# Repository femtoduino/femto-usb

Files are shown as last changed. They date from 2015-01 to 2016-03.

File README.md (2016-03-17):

femto-usb
=========



FemtoUSB - Atmel ARM Cortex M0+ (SAMD21), 256KB @ 48MHz, 3V3

This micro controller is designed as a basic starting point for those interested in ARM designs (especially if you are transitioning from 8-bit AVR chips).

We use Atmel's ARM Cortex M0+ offering, the ATSAMD21E18A. The schematic follows the suggested design found in the SAM D21 data sheet.

## Arduino Setup (TLDR)

Arduino compatible when using FemtoUSB (ARM) r1.0.1, with RGB LED.

Just add us to your Arduino IDE. See README https://github.com/femtoio/ArduinoCore-atsamd21e18a/tree/atsamd21e18a_variant

## Why Atmel?
Atmel has some of the best support for the open-source hardware community. They offer proper documentation, excellent chip performance, and a great foundation via the Atmel Software Framework.
Did we mention how easy it is to get started with ARM using ATMEL?

## Key similarities, and differences between 8-bit AVR chips, and newer ARM chips

So, you've been working with Arduino boards for a while now, but want to get into ARM chips right? How difficult can it be?

As it turns out, it's much less so today than it was a short time ago. Thankfully, most micro controllers have a similar set of requirements:

1. Add in some snubbing caps, as per the chip's data sheet.
2. Add in some resistors, as per the chip's data sheet.
3. Add the reset circuit.
4. Add a "power on" LED, making sure to wire up voltage and ground pins correctly.
5. Hook up a USB port, as per the chip's data sheet.
6. Burn a boot loader.

You can of course, add in a reverse current protection circuit, a crystal clock source for chips that don't have an internal one (or if you want a faster clock source), some fancy peripheral additions, etc... but at the most basic design, both 8-bit AVR chips and ARM chips have similar design requirements.

However, here's where we will draw an imaginary line, and now distinguish between 8-bit AVRs and 16/32-bit ARM chips.

When working with ARM chips, you will need a programmer dongle to initially burn a boot loader. 
"Serial Wire Debug" seems to be the most basic form of the [JTAG](http://en.wikipedia.org/wiki/Joint_Test_Action_Group) interface - something provided by all ARM chips. 
This is akin to the "Ardiuno ISP" mode of programming. 
Keep in mind, however, not all chips "talk the same" between the chip and a dongle. Kind of like how two people can have the same interface (vocal chords), but speak different languages. 
Fortunately, it seems Atmel's SAM D21 chips talk "CMSIS" [Cortex Microcontroller Software Interface Standard](http://www.arm.com/products/processors/cortex-m/cortex-microcontroller-software-interface-standard.php), which is a vendor-independent hardware abstraction layer for the Cortex-M processor series.
This is another great reason to use Atmel's line of ARM chips, for what it's worth.

The pins used to provide a JTAG connection vary depending on the ARM chip used, and provide more debugging features when more pins are added.
For the most part, JTAG "Serial Wire Debug" establishes these five (5) connections:

* Ground
* Voltage Reference (Does not supply voltage, you must tie your regulated voltage source to this line when connecting a dongle to a board)
* RESET
* SWCLK (Serial Wire Clock, sometimes overlaid on the "TCK" pin)
* SWDIO (Serial Wire Debug Input/Output, sometimes overlaid on the "TMS" pin)

Your programming dongle should have a data sheet telling you the pin out provided, so you can wire it to your board accordingly.

Another key difference, *and a very important one at that*, is the voltage!

You may be used to 5V logic levels working with Atmel's 8-bit chips... but 5V can be utterly destructive to an ARM chip, as they are meant to work with less power.
The usual voltage range for Atmel's line of ARM chips is somewhere between 1.8V to 3.3V. 
Failure to heed this notice will likely result in the production of a tiny paperweight, instead of a micro controller. 

Ok, I suppose we can move forward. Let's get everything we need to build one.

## Building your own board
The following instructions should help you build your own ARM board. Please follow common workplace and ESD safety practices, and ensure proper ventilation. Solder paste, solder rework, PCB fibers, hot air rework nozzles, soldering irons, and so on, should all be handled with proper safety in mind.
Please observe you local materials safety and disposal laws/guides. We assume no liability whatsoever. Not even. Just no.

### Equipment
As with all ARM chips, you will benefit greatly from having a programmer dongle.
Some vendors lock their chips behind really expensive software tools, and even more expensive programmer dongles ($200+). 
Oh, and have fun trying to get their proprietary stuff working with your open source setup.

Thankfully, Atmel offers their ATMEL-ICE programmer at a reasonable price of [about $85 USD](http://store.atmel.com/PartDetail.aspx?q=p:10500375#tc:description).
I hear you can get them much cheaper without the case, though don't expect it to come with ribbon cables if you go the cheap route.

Please source the following equipment:
* An [ATMEL-ICE programmer](http://www.atmel.com/tools/atatmel-ice.aspx)
* A Windows, Mac OS X, or Linux machine. (Though you may initially require a Windows machine to burn the SAM-BA bootloader using Atmel Studio.)
* Two (2) USB "Micro B" cable. Some cables are less than useless. Try to use ones without a choke if you get any trouble with USB connections.
* Round jumper wires.
* Bread board.
* A reflow station. We use a [Sparkfun Hot-air Rework Station](https://www.sparkfun.com/products/10706)
* A good pair of tweezers. See [Adafruit's offering](http://www.adafruit.com/products/421?gclid=CN-E8eah5MMCFU9efgodj3IAJQ)
* [Helping third hand](http://www.adafruit.com/product/291)
* A multimeter.

Additionally, you will need the following supplies:
* Low temp Lead-free solder paste. We recommend [Pieco's  paste press dispenser bundle with the ChipQuik T5 paste](https://www.tindie.com/products/Pieco/paste-press/) or similar.  
* Some PCBs. You can order them from [OSH Park](https://oshpark.com/shared_projects/F0wPGZvV), or open up the Eagle PCB designs to modify and make your own (see the FemtoUSB_r1.0.0 folder, open up the femtoUSB_r1.0.0_TQFP board and schematic)
* The SMD components. [Thanks Octopart!](https://octopart.com/bom-lookup/UgbhotEt) ...the gerbers and parts lists can also be found within the `FemtoUSB_r1.0.0/femtoUSB_r1.0.0_TQFP/` folder

### Software tools
On windows, you will need
* Atmel Studio (6.2.x as of the time of this writing)

On Mac OS X, and Linux
* [Terry Guo's GNU ARM Embedded Toolchain.](https://launchpad.net/~terry.guo/+archive/ubuntu/gcc-arm-embedded) (Ubuntu user's can add a PPA and have the apt-get package manager install it)
* Legit command line ninja skills.
* Make tools.

For any machine you are on, you will also need the following:

* [Atmel Software Framework (ASF)](http://www.atmel.com/tools/avrsoftwareframework.aspx?tab=overview)
* [Atmel SAM-BA In-system Programmer](http://www.atmel.com/tools/ATMELSAM-BAIN-SYSTEMPROGRAMMER.aspx)
* [Atmel AT07175: SAM-BA Bootloader for SAM D21](http://www.atmel.com/devices/atsamd21e18a.aspx?tab=documents) ...Note, this is what actually gets programmed on to the chip so we can load stuff via USB instead.

### Assembling a board, or three.
For the most part, try not to make a mess of solder paste everywhere. Add just enough to cover the solder pads with a thin layer, and place the correct part according to the femtoUSB_r1.0.0_TQFP_parts.csv spread sheet.
If you don't have the 4-layer or more version of Eagle PCB, you can also look at the femtoUSB_r1.0.0_TQFP.pdf file for schematics and board drawings. See `FemtoUSB_r1.0.0/femtoUSB_r1.0.0_TQFP/`

Once you have everything assembled, make sure your board is secured by the "helping third hand" tool, and remove any nozzle attachments from your reflow station to get the widest air flow. 
Heat up your reflow station to around 200c - 210c or so. The low temperature lead-free solder paste should not require too much heat. Air flow should be kept low (I dial it down to level 4 on my Sparkfun Hot-air Rework station).
Go ahead and adjust the temperature and air flow as you see fit. A constant stream of hot air should reflow stuff within a minute or less.

Be certain to keep the air flow on the USB connection a bit longer than the rest of the board, as the pads underneath the USB connector may take a few seconds longer to heat up.

*Allow your boards to cool down on their own before handling!*

### Testing and programming
Grab you multimeter, switch it to the "open circuit" checking mode (you know, the one that beeps when touch the two leads).
Test between the GND (Ground) pin and all other pins to assert there are no shorts between Ground and the rest of the pins. 
Do the same between voltage and other pins. As a last step, you can also test by steping pegs, (testing between two concurrent pins, moving up by one pin at a time).
This last step is mostly necessary if you have a hard time checking the board for shorts or gaps visually.

Now, it's time to give our board(s) a bootloader!

Wire the following pins together, tying the two "GND" pins from the ATMEL-ICE programmer dongle on to a breadboard, so you can use a single wire from the breadboard GND line to the board's GND pin.
Additionally, you will need to make sure the board's 3V3 (regulated) volatage pin is tied to the programmer dongle's VTG (voltage reference) pin, as the programmer dongle does *not* supply voltage. It merely detects the voltage level with the VREF line.

*DO NOT MIX UP THE "SAM" PORT WITH THE "AVR" PORT, AS THE PINOUT IS DIFFERENT!*

| ATMEL-ICE "SAM" port | Your Board |
|---|---|
| SWDCLK (SAM Pin 4) | SWDCLK (PA31)  |
| SWDIO (SAM Pin 2) | SWDIO (PA30) |
| nRST (SAM Pin 10, labeled "0") | RESET |
| VTG (SAM Pin 1) | 3V3 (Regulated)|
| GND (SAM Pin 3, 5) | GND |

#### Windows
Open up Atmel Studio on your Windows machine, plug in the USB cable for your board, plug in the USB cable for your programmer dongle.
Your board should power on, the programmer should have both a red LED and a green LED powered on.

If only the red programmer dongle LED turns on, check for loose connections and check for any solder issues on your board. At worse, build another one with a different PCB and try again.
Don't worry about the semi-on blue LED on your board. That's just the SWDCLK line. You can unsolder it if it bugs you. 

Once you have a good board hooked up, and Atmel Studio running, open up the Device Programmer dialog by navigating to the Tools -> Device Programmer menu item.

In the Device Programmer dialog, select "ATMEL-ICE" as the tool, select "ATSAMD21E18A" as the device (double check to be certain you read this right), and select "SWD" as the interface. 
Click the "Apply" button. Set the "SWD Clock" value to anything from 32KHz to 2MHz and click "Set".
2MHz is plenty fast, but if you ever run into issues reading the chip, try going as low as 32KHz.

You should now click the "Read" button under "Device Signature" to see if you get back a hex value. The board's blue LED will go from semi-off, to bright blue.
If you get a message saying your device is unreadable, double check your connections, double check your solder work, and try again.

Assuming you got back a hex value under "Device Signature", congrats! You appear to have a functional board!

Let's now burn the bootloader.

Click the "Memories" section of the Device Programmer dialog. In the "Flash" area, use the file navigator button to browse to the downloaded (and extracted) `Atmel-42366-SAM-BA-Bootloader-for-SAM-D21_ApplicationNote_AT07175/load sam-ba/samd21e18a/` folder, and select `samd21_sam_ba_usbcdc.hex`
Assert the "Erase Flash before programming" and "Verify Flash after programming" checkboxes are checked. Click "Program". After a brief moment, the Device Programmer dialog should come back with:

```
Erasing device... OK
Programming Flash...OK
Verifying Flash...OK
```

Success! You now have a board with the SAM-BA bootloader! If you're on a Windows machine, you may notice Windows will now attempt to install drivers for the new device. The Windows driver install tool should succeed in finding the correct drivers.
You can now see your board on Linux/Mac as well. Simply plug it in via USB, and run the 'lsusb' command from a terminal. You will see an Atmel 'SAM-BA' device listing.

#### GNU/Linux (Ubuntu)

You will need to install Terry Guo's arm-none-eabi-* toolchain, OpenOCD, and the build-essentails package.

To load stuff over USB CDC, you will need either Atmel's SAM-BA utility, or the 'arduino' branch of the BOSSA utility (compiled from source). See https://github.com/femtoio/BOSSA

```
# Thanks to Patryk Jaworski for a wonderful blog article
# http://regalis.com.pl/en/arm-cortex-stm32-gnulinux/
openocd -f /path/to/boardconfig.cfg
```
Then, in a separate terminal:
```
telnet localhost 4444
```
...Run the following within telnet:
```
reset halt
flash write_image erase yourfile.hex
reset run
```

## Next Steps
We are working on getting Arduino integration working, along with other non-Arduino tools to load stuff via USB. Stay tuned!

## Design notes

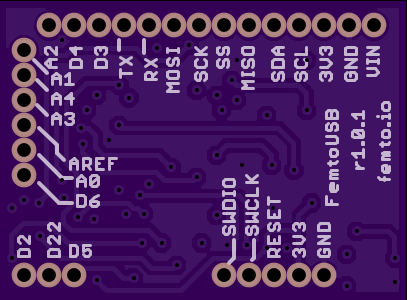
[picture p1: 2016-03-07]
FemtoUSB_r1.0.1/femtoUSB_RGB_r1.0.1_bottom.png

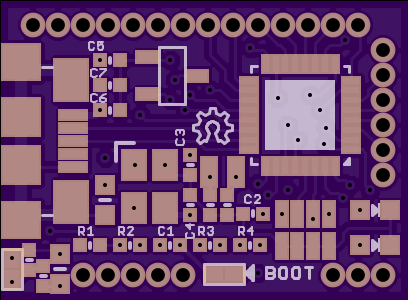
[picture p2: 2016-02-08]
FemtoUSB_r1.0.1/femtoUSB_r1.0.1_top.png

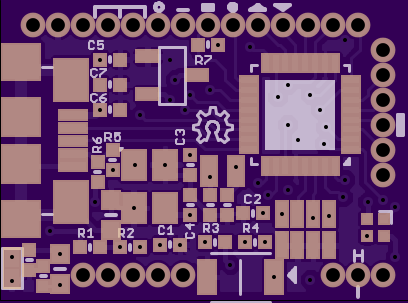
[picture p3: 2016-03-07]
FemtoUSB_r1.0.1/femtoUSB_RGB_r1.0.1_top.png

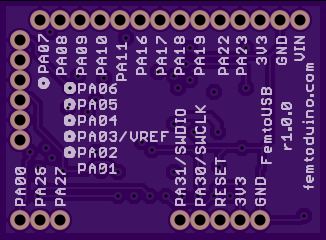
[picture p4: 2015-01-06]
FemtoUSB_r1.0.1/femtoUSB_bottom.png

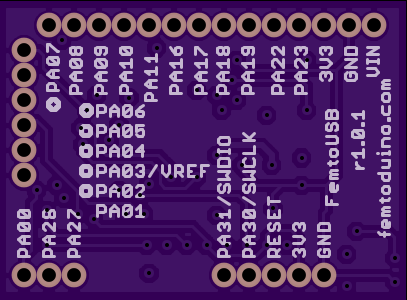
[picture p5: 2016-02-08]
FemtoUSB_r1.0.1/femtoUSB_r1.0.1_bottom.png

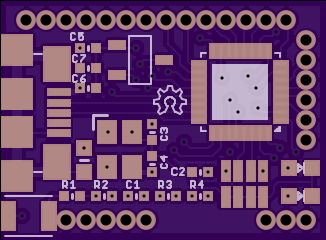
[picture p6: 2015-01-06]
FemtoUSB_r1.0.1/femtoUSB_top.png

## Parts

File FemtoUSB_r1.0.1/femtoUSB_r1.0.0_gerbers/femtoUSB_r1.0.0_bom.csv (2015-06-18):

Qty | Value | Device | Package | Parts | Description | DIGIKEY_PART/MNF_PART
1 |  | FERRITE_0603MP | _0603MP | FB1 | Ferrite Bead | BLM18RK102SN1D
1 | 0.1uF | CAP_CERAMIC_0402MP | _0402MP | C1 | Ceramic Capacitors | GRM033C80J104KE84D
1 | 0.1uF | KEMET_CERAMIC_CAPACITOR_ARRAY_1X4 | CAPACITOR_ARRAY_1206_MONO_1X4 | C_ARR1 |  | CA064C104K4RACTU
1 | 0.47uF | CAP_CERAMIC_0402MP | _0402MP | C7 | Ceramic Capacitors | C1005X5R1C474K050BC
1 | 10K | RESISTOR_0402MP | _0402MP | R2 | Resistors | CRCW040210K0JNEDHP
1 | 1X14_ROUND | 1X14_ROUND | 1X14_ROUND | U$6
1 | 1X3_ROUND | 1X3_ROUND | 1X3_ROUND | U$7
1 | 1X5_ROUND | 1X5_ROUND | 1X5_ROUND | U$9
1 | 1X6_ROUND | 1X6_ROUND | 1X6_ROUND | U$12
2 | 2.2uF | CAP_CERAMIC_0402MP | _0402MP | C5, C6 | Ceramic Capacitors | C1005X5R1C225K050BC
1 | 48MHz | TSX-3225 | TSX-3225 | EPSON_TSX1 |  | FA-238 48.0000MB-K3
3 | 330 | RESISTOR_0402MP | _0402MP | R1, R3, R4 | Resistors | CRCW0402330RJNED
1 | 4.7uF | CAP_CERAMIC_0402MP | _0402MP | C2 | Ceramic Capacitors | C1005X5R1A475K050BC
2 | 10pF | CAP_CERAMIC_0402MP | _0402MP | C3, C4 | Ceramic Capacitors | GRM0335C1E100JA01D
1 | ATSAMD21E18A-MUT | ATSAMD21E18A-MUT | QFN32 | IC1 | This is the ATMEL SAMD21E QFN-32 (ATSAMD21E18A-MU). The QFP version is ATSAMD21E18A-AU | ATSAMD21E18A-MUT
1 | BLUE | LED0603_NOOUTLINE | CHIPLED_0603_NOOUTLINE | LED2 | LED | 350-2037-1-ND
1 | MCP1700T-3302E/TT | MCP1700T-3302E/TT | MCP1700T-3302E/TT | LDO_VREG |  | MCP1700T-3302E/TT
1 | YELLOW | LED0603_NOOUTLINE | CHIPLED_0603_NOOUTLINE | LED1 | LED | 350-2032-1-ND
1 | USB_MICROB | USB_MICROB | USB_MICROB_PACKAGE | MICRO_B_USB | This is the hirose ZX62-B-5PA(11) MICRO-USB B Type female connection. | ZX62-B-5PA(11)
1 | 10uH | INDUCTOR_0603MP | _0603MP | L1 |  | LQM18FN100M00D
2 | 10uF | CAP_CERAMIC_0402MP | _0402MP | C8, C9 |  | CL05A106MP5NUNC

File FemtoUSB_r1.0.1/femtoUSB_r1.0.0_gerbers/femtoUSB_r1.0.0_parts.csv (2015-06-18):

Part | Value | Device | Package | Description
C1 | 0.1uF | CAP_CERAMIC_0402MP | _0402MP | Ceramic Capacitors
C2 | 4.7uF | CAP_CERAMIC_0402MP | _0402MP | Ceramic Capacitors
C3 | 10pF | CAP_CERAMIC_0402MP | _0402MP | Ceramic Capacitors
C4 | 10pF | CAP_CERAMIC_0402MP | _0402MP | Ceramic Capacitors
C5 | 2.2uF | CAP_CERAMIC_0402MP | _0402MP | Ceramic Capacitors
C6 | 2.2uF | CAP_CERAMIC_0402MP | _0402MP | Ceramic Capacitors
C7 | 0.47uF | CAP_CERAMIC_0402MP | _0402MP | Ceramic Capacitors
C8 | 10uF | CAP_CERAMIC_0402MP | _0402MP | Ceramic Capacitors
C9 | 10uF | CAP_CERAMIC_0402MP | _0402MP | Ceramic Capacitors
C_ARR1 | 0.1uF | KEMET_CERAMIC_CAPACITOR_ARRAY_1X4 | CAPACITOR_ARRAY_1206_MONO_1X4
EPSON_TSX1 | 48MHz | TSX-3225 | TSX-3225 | FA-238 48.0000MB-K3
FB1 |  | FERRITE_0603MP | _0603MP | Ferrite Bead
IC1 | ATSAMD21E18A-MUT | ATSAMD21E18A-MUT | QFN32 | This is the ATMEL SAMD21E QFN-32. ATSAMD21E18A
L1 | 10uH | INDUCTOR_0603MP | _0603MP | Fixed Inductor.
LDO_VREG | LM3480 | LM3480 | LM3480
LED1 | RED | LED0603_NOOUTLINE | CHIPLED_0603_NOOUTLINE | LED
LED2 | GREEN | LED0603_NOOUTLINE | CHIPLED_0603_NOOUTLINE | LED
MICRO_B_USB | USB_MICROB | USB_MICROB | USB_MICROB_PACKAGE | This is the hirose ZX62-B-5PA(11) MICRO-USB B Type female connection.
R1 | 330 | RESISTOR_0402MP | _0402MP | Resistors
R2 | 10K | RESISTOR_0402MP | _0402MP | Resistors
R3 | 330 | RESISTOR_0402MP | _0402MP | Resistors
R4 | 330 | RESISTOR_0402MP | _0402MP | Resistors
U$6 | 1X14_ROUND | 1X14_ROUND | 1X14_ROUND | 1.27mm Pitch
U$7 | 1X3_ROUND | 1X3_ROUND | 1X3_ROUND | 1.27mm Pitch
U$9 | 1X5_ROUND | 1X5_ROUND | 1X5_ROUND | 1.27mm Pitch
U$12 | 1X6_ROUND | 1X6_ROUND | 1X6_ROUND | 1.27mm Pitch

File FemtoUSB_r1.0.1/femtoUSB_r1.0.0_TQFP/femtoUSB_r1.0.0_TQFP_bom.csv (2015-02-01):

Qty | Value | Device | Package | Parts | Description | DIGIKEY_PART
1 |  | BLM18RK102SN1D | _0603MP | FB1 | Ferrite Bead | 490-5228-1-ND
1 | 0.1uF | C1005X7R1A104K050BB | _0402MP | C1 | Ceramic Capacitors | 445-4958-1-ND
1 | 0.1uF | CA064C104K4RACTU | CAPACITOR_ARRAY_1206_MONO_1X4 | C_ARR1 |  | 399-8243-1-ND
1 | 0.47uF | C1005X5R1C474K050BC | _0402MP | C7 | Ceramic Capacitors | 445-4976-1-ND
1 | 10K | CRCW040210K0JNEDHP | _0402MP | R2 | Resistors | 541-10KYACT-ND
1 | DNP | 1X14_ROUND | 1X14_ROUND | U$6
1 | DNP | 1X3_ROUND | 1X3_ROUND | U$7
1 | DNP | 1X5_ROUND | 1X5_ROUND | U$9
1 | DNP | 1X6_ROUND | 1X6_ROUND | U$12
2 | 2.2uF | C1005X5R1C225K050BC | _0402MP | C5, C6 | Ceramic Capacitors | 445-9085-1-ND
1 | 26MHz | TSX-3225 26.0000MF09Z-AC3 | TSX-3225 | EPSON_TSX1 |  | SER3627CT-ND
3 | 330 | CRCW0402330RJNED | _0402MP | R1, R3, R4 | Resistors | 541-330JCT-ND
1 | 4.7uF | C1005X5R1A475K050BC | _0402MP | C2 | Ceramic Capacitors | 445-13820-1-ND
2 | 9pF | C1005C0G1H090C050BA | _0402MP | C3, C4 | Ceramic Capacitors | 445-4894-1-ND
1 | ATSAMD21E18A-AU | ATSAMD21E18A-AU | 32-TQFP | IC1 |  | ATSAMD21E18A-AU-ND
1 | BLUE | 598-8091-107F | CHIPLED_0603_NOOUTLINE | LED2 | Blue LED | 350-2037-1-ND
1 | MCP1700T-3302E/TT | MCP1700T-3302E/TT | MCP1700T-3302E/TT | LDO_VREG |  | MCP1700T3302ETTCT-ND
1 | DNP | SPST_SMD | SPST_SMD | BTN
1 | YELLOW | 598-8040-107F | CHIPLED_0603_NOOUTLINE | LED1 | Yellow LED | 350-2032-1-ND
1 | USB_MICROB | ZX62-B-5PA(11) | USB_MICROB_PACKAGE | MICRO_B_USB | This is the hirose ZX62-B-5PA(11) MICRO-USB B Type female connection. | H11634CT-ND
1 | 10uH | LQM18FN100M00D | _0603MP | L1 |  | 490-4025-1-ND
2 | 10uF | CL05A106MP5NUNC | _0402MP | C8, C9 |  | 1276-1450-1-ND

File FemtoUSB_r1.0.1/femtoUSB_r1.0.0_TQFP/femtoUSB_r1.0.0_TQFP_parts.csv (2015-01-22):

Part | Value | Device | Package | Description | DIGIKEY_PART
BTN | OMRON B3U-300P(M) | TACTILE_SWITCH_NO_GND_NO_BOSS | SIDE_ACT_NO_GND_NO_BOSS
C1 | 0.1uF | CAP_CERAMIC_0402MP | _0402MP | Ceramic Capacitors
C2 | 4.7uF | CAP_CERAMIC_0402MP | _0402MP | Ceramic Capacitors
C3 | 9pF | CAP_CERAMIC_0402MP | _0402MP | Ceramic Capacitors
C4 | 9pF | CAP_CERAMIC_0402MP | _0402MP | Ceramic Capacitors
C5 | 2.2uF | CAP_CERAMIC_0402MP | _0402MP | Ceramic Capacitors
C6 | 2.2uF | CAP_CERAMIC_0402MP | _0402MP | Ceramic Capacitors
C7 | 0.47uF | CAP_CERAMIC_0402MP | _0402MP | Ceramic Capacitors
C_ARR1 | 0.1uF | KEMET_CERAMIC_CAPACITOR_ARRAY_1X4 | CAPACITOR_ARRAY_1206_MONO_1X4 |  | 399-8243-1-ND
EPSON_TSX1 | 32MHz | TSX-3225 | TSX-3225 |  | TSX-3225 32.0000MF15X-B-ND
FB1 |  | FERRITE_0603MP | _0603MP | Ferrite Bead
IC1 | ATSAMD21E18A-AU | ATSAMD21E18A-AU | 32-TQFP
LDO_VREG | MCP1700T-3302E/TT | MCP1700T-3302E/TT | MCP1700T-3302E/TT
LED1 | RED | LED0603_NOOUTLINE | CHIPLED_0603_NOOUTLINE | LED
LED2 | GREEN | LED0603_NOOUTLINE | CHIPLED_0603_NOOUTLINE | LED
MICRO_B_USB | USB_MICROB | USB_MICROB | USB_MICROB_PACKAGE | This is the hirose ZX62-B-5PA(11) MICRO-USB B Type female connection.
R1 | 330 | RESISTOR_0402MP | _0402MP | Resistors
R2 | 10K | RESISTOR_0402MP | _0402MP | Resistors
R3 | 330 | RESISTOR_0402MP | _0402MP | Resistors
R4 | 330 | RESISTOR_0402MP | _0402MP | Resistors
U$6 | 1X14_ROUND | 1X14_ROUND | 1X14_ROUND
U$7 | 1X3_ROUND | 1X3_ROUND | 1X3_ROUND
U$9 | 1X5_ROUND | 1X5_ROUND | 1X5_ROUND
U$12 | 1X6_ROUND | 1X6_ROUND | 1X6_ROUND

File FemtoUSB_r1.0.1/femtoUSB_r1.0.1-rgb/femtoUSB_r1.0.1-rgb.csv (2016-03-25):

Qty | Value | Device | Package | Parts | Description | MFR_ID
1 |  | FERRITE_0603MP | _0603MP | FB1 | Ferrite Bead | BLM18RK102SN1D
1 | DNP | SPST_SMD | SPST_SMD | SJ_RESET
1 | 0.1uF | CAP_CERAMIC_0402MP | _0402MP | C1 | Ceramic Capacitors | C1005X7R1A104K050BB
1 | 0.1uF | KEMET_CERAMIC_CAPACITOR_ARRAY_1X4 | CAPACITOR_ARRAY_1206_MONO_1X4 | C_ARR |  | CA064C104K4RACTU
1 | 0.47uF | CAP_CERAMIC_0402MP | _0402MP | C7 | Ceramic Capacitors | C1005X5R1C474K050BC
1 | 100K | RESISTOR_0402MP | _0402MP | R6 | Resistors | ERJ-2RKF1003X
1 | 10K | RESISTOR_0402MP | _0402MP | R2 | Resistors | CRCW040210K0JNEDHP
2 | 10uF | CAP_CERAMIC_0402MP | _0402MP | C8, C9 | Ceramic Capacitors | CL05A106MP5NUNC
1 | 10uH | INDUCTOR_0603MP | _0603MP | L1 | Inductors | LQM18FN100M00D
1 | DNP | 1X14_ROUND | 1X14_ROUND | PIN_1X14
1 | DNP | 1X3_ROUND | 1X3_ROUND | PIN_1X3
1 | DNP | 1X5_ROUND | 1X5_ROUND | PIN_1X5
1 | DNP | 1X6_ROUND | 1X6_ROUND | PIN_1X6
2 | 2.2uF | CAP_CERAMIC_0402MP | _0402MP | C5, C6 | Ceramic Capacitors | C1005X5R1C225K050BC
5 | 330 | RESISTOR_0402MP | _0402MP | R1, R3, R4, R5, R7 | Resistors | CRCW0402330RJNED
1 | 4.7uF | CAP_CERAMIC_0402MP | _0402MP | C2 | Ceramic Capacitors | C1005X5R1A475K050BC
1 | 48MHz | TSX-3225 | TSX-3225 | EPSON_TSX1 |  | FA-238 48.0000MB-K3
2 | 4pF | CAP_CERAMIC_0402MP | _0402MP | C10, C11 | Ceramic Capacitors | GJM1555C1H4R0CB01D
2 | 10pF | CAP_CERAMIC_0402MP | _0402MP | C3, C4 | Ceramic Capacitors | VJ0402A100FXACW1BC
1 | ABS06-107-32.768KHZ-T | ABS06-107-32.768KHZ-T | ABS06-107-32.768KHZ-T | OSC32K | ABS06-107-32.768kHz-T Crystal Oscillator | ABS06-107-32.768kHz-T
1 | ATSAMD21E18A-MUT | ATSAMD21E18A-MUT | QFN32 | IC1 | This is the ATMEL SAMD21E QFN-32. ATSAMD21E18A | ATSAMD21E18A-MUT
1 | LRTB_R48G | LRTB_R48G | LRTB_R48G | RGBLED |  | LRTB R48G
1 | MCP1700T-3302E/TT | MCP1700T-3302E/TT | MCP1700T-3302E/TT | LDO_VREG | Microchip LDO "MCP1700" in a 3-Pin SOT-23 package. | MCP1700T-3302E/TT
1 | TACTILE_SWITCH_NO_GND_NO_BOSS | TACTILE_SWITCH_NO_GND_NO_BOSS | SIDE_ACT_NO_GND_NO_BOSS | BTN_BOOT |  | B3U-3000PM
1 | USB_MICROB | USB_MICROB | USB_MICROB_PACKAGE | MICRO_B_USB | This is the hirose ZX62-B-5PA(11) MICRO-USB B Type female connection. | ZX62-B-5PA(11)

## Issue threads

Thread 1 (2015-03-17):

Arduino Hardware Core

pral2a, 2015-03-17:
We are really interested on developing and Arduino Hardware Core for the SAMD21 [Smart Citizen Kit](http://smartcitizen.me) project.

We are amazed by your idea of using ATMEL SAM-BA bootloader instead of the Arduino Zero EDBG approach.

https://github.com/femtoduino/femto-usb#next-steps

Do you think there is the possibility of joining forces on finishing this development?

Here is our main project repository

https://github.com/fablabbcn/Smart-Citizen-Kit

bobricius, 2015-03-17:
Hi, I tested today upload from arduino IDE 1.5.8.3 to atsamd21 xplained board and it working, also I flash provided bootloader and with this I canupload sketch to sam21 withou edbg chip from native usb port.

pral2a, 2015-03-17:
Thanks for the quick reply,

What cores did you use to target the atsamd21 from the Arduino IDE?

Thanks

bobricius, 2015-03-17:
I just select arduino zero from board menu, core is samd, you need ide from arduino.org not from arduino.cc
chaos begin .... two arduinos...

zrecommerce, 2015-03-18:
Really cool find, @bobricius! I'll verify with a FemtoUSB. I had to revise it once more to break out pin PA15 so the board can be put into boot loader moad after loading a sketch. The board I have at hand should be good.enough to test though, as the SAM-BA boot loader can be loaded.

zrecommerce, 2015-03-18:
FYI, found this while perusing `hardware/arduino/samd/variants/arduino_zero/variant.cpp` ...seems to be the Port/Pin map to Arduino Zero pinout.

```
/*
 *
 * + Pin number +  ZERO Board pin  |  PIN   | Label/Name      | Comments (* is for default peripheral in use)
 * +------------+------------------+--------+-----------------+------------------------------
 * |            | Digital Low      |        |                 |
 * +------------+------------------+--------+-----------------+------------------------------
 * | 0          | 0 -> RX          |  PA10  |                 | EIC/EXTINT[10] ADC/AIN[18] PTC/X[2] *SERCOM0/PAD[2] TCC1/WO[0] TCC0/WO[2]
 * | 1          | 1 <- TX          |  PA11  |                 | EIC/EXTINT[11] ADC/AIN[19] PTC/X[3] *SERCOM0/PAD[3] SERCOM2/PAD[3] TCC1/WO[1] TCC0/WO[3]
 * | 2          | ~2               |  PA08  |                 | EIC/NMI ADC/AIN[16] PTC/X[0] SERCOM0/PAD[0] SERCOM2/PAD[0] *TCC0/WO[0] TCC1/WO[2]
 * | 3          | ~3               |  PA09  |                 | EIC/EXTINT[9] ADC/AIN[17] PTC/X[1] SERCOM0/PAD[1] SERCOM2/PAD[1] *TCC0/WO[1] TCC1/WO[3]
 * | 4          | ~4               |  PA14  |                 | EIC/EXTINT[14] SERCOM2/PAD[2] SERCOM4/PAD[2] TC3/WO[0] *TCC0/WO[4]
 * | 5          | ~5               |  PA15  |                 | EIC/EXTINT[15] SERCOM2/PAD[3] SERCOM4/PAD[3] TC3/WO[1] *TCC0/WO[5]
 * | 6          | ~6               |  PA20  |                 | EIC/EXTINT[4] PTC/X[8] SERCOM5/PAD[2] SERCOM3/PAD[2] TC7/WO[0] *TCC0/WO[6]
 * | 7          | ~7               |  PA21  |                 | EIC/EXTINT[5] PTC/X[9] SERCOM5/PAD[3] SERCOM3/PAD[3] TC7/WO[1] *TCC0/WO[7]
 * +------------+------------------+--------+-----------------+------------------------------
 * |            | Digital High     |        |                 |
 * +------------+------------------+--------+-----------------+------------------------------
 * | 8          | ~8               |  PA06  |                 | EIC/EXTINT[6] PTC/Y[4] ADC/AIN[6] AC/AIN[2] SERCOM0/PAD[2] *TCC1/WO[0]
 * | 9          | ~9               |  PA07  |                 | EIC/EXTINT[7] PTC/Y[5] DC/AIN[7] AC/AIN[3] SERCOM0/PAD[3] *TCC1/WO[1]
 * | 10         | ~10              |  PA18  |                 | EIC/EXTINT[2] PTC/X[6] SERCOM1/PAD[2] SERCOM3/PAD[2] *TC3/WO[0] TCC0/WO[2]
 * | 11         | ~11              |  PA16  |                 | EIC/EXTINT[0] PTC/X[4] SERCOM1/PAD[0] SERCOM3/PAD[0] *TCC2/WO[0] TCC0/WO[6]
 * | 12         | ~12              |  PA19  |                 | EIC/EXTINT[3] PTC/X[7] SERCOM1/PAD[3] SERCOM3/PAD[3] *TC3/WO[1] TCC0/WO[3]
 * | 13         | ~13              |  PA17  | LED             | EIC/EXTINT[1] PTC/X[5] SERCOM1/PAD[1] SERCOM3/PAD[1] *TCC2/WO[1] TCC0/WO[7]
 * | 14         | GND              |        |                 |
 * | 15         | AREF             |  PA03  |                 | *DAC/VREFP PTC/Y[1]
 * | 16         | SDA              |  PA22  |                 | EIC/EXTINT[6] PTC/X[10] *SERCOM3/PAD[0] SERCOM5/PAD[0] TC4/WO[0] TCC0/WO[4]
 * | 17         | SCL              |  PA23  |                 | EIC/EXTINT[7] PTC/X[11] *SERCOM3/PAD[1] SERCOM5/PAD[1] TC4/WO[1] TCC0/WO[5]
 * +------------+------------------+--------+-----------------+------------------------------
 * |            |SPI (Legacy ICSP) |        |                 |
 * +------------+------------------+--------+-----------------+------------------------------
 * | 18         | 1                |  PA12  | MISO            | EIC/EXTINT[12] SERCOM2/PAD[0] *SERCOM4/PAD[0] TCC2/WO[0] TCC0/WO[6]
 * | 19         | 2                |        | 5V0             |
 * | 20         | 3                |  PB11  | SCK             | EIC/EXTINT[11]                *SERCOM4/PAD[3] TC5/WO[1] TCC0/WO[5]
 * | 21         | 4                |  PB10  | MOSI            | EIC/EXTINT[10]                *SERCOM4/PAD[2] TC5/WO[0] TCC0/WO[4]
 * | 22         | 5                |        | RESET           |
 * | 23         | 6                |        | GND             |
 * +------------+------------------+--------+-----------------+------------------------------
 * |            | Analog Connector |        |                 |
 * +------------+------------------+--------+-----------------+------------------------------
 * | 24         | A0               |  PA02  |                 | EIC/EXTINT[2] *ADC/AIN[0] PTC/Y[0] DAC/VOUT
 * | 25         | A1               |  PB08  |                 | EIC/EXTINT[8] *ADC/AIN[2] PTC/Y[14] SERCOM4/PAD[0] TC4/WO[0]
 * | 26         | A2               |  PB09  |                 | EIC/EXTINT[9] *ADC/AIN[3] PTC/Y[15] SERCOM4/PAD[1] TC4/WO[1]
 * | 27         | A3               |  PA04  |                 | EIC/EXTINT[4] *ADC/AIN[4] AC/AIN[0] PTC/Y[2] SERCOM0/PAD[0] TCC0/WO[0]
 * | 28         | A4               |  PA05  |                 | EIC/EXTINT[5] *ADC/AIN[5] AC/AIN[1] PTC/Y[5] SERCOM0/PAD[1] TCC0/WO[1]
 * | 29         | A5               |  PB02  |                 | EIC/EXTINT[2] *ADC/AIN[10] PTC/Y[8] SERCOM5/PAD[0] TC6/WO[0]
 * +------------+------------------+--------+-----------------+------------------------------
 * |            | LEDs             |        |                 |
 * +------------+------------------+--------+-----------------+------------------------------
 * | 30         |                  |  PB03  | RX              |
 * | 31         |                  |  PA27  | TX              |
 * +------------+------------------+--------+-----------------+------------------------------
 * |            | USB              |        |                 |
 * +------------+------------------+--------+-----------------+------------------------------
 * | 32         |                  |  PA28  | USB HOST ENABLE |
 * | 33         |                  |  PA24  | USB_NEGATIVE    | USB/DM
 * | 34         |                  |  PA25  | USB_POSITIVE    | USB/DP
 * +------------+------------------+--------+-----------------+------------------------------
 * |            | EDBG             |        |                 |
 * +------------+------------------+--------+-----------------+------------------------------
 * | 35         |                  |  PB22  | EDBG_UART TX    | SERCOM5/PAD[2]
 * | 36         |                  |  PB23  | EDBG_UART RX    | SERCOM5/PAD[3]
 * +------------+------------------+--------+-----------------+------------------------------
 * | 37         |                  |  PA22  | EDBG_SDA        | SERCOM3/PAD[0]
 * | 38         |                  |  PA23  | EDBG_SCL        | SERCOM3/PAD[1]
 * +------------+------------------+--------+-----------------+------------------------------
 * | 39         |                  |  PA19  | EDBG_MISO       | SERCOM1/PAD[3]
 * | 40         |                  |  PA16  | EDBG_MOSI       | SERCOM1/PAD[0]
 * | 41         |                  |  PA18  | EDBG_SS         | SERCOM1/PAD[2]
 * | 42         |                  |  PA17  | EDBG_SCK        | SERCOM1/PAD[1]
 * +------------+------------------+--------+-----------------+------------------------------
 * | 43         |                  |  PA13  | EDBG_GPIO0      | EIC/EXTINT[13] *TCC2/WO[1] TCC0/WO[7]
 * | 44         |                  |  PA21  | EDBG_GPIO1      | Pin 7
 * | 45         |                  |  PA06  | EDBG_GPIO2      | Pin 8
 * | 46         |                  |  PA07  | EDBG_GPIO3      | Pin 9
 * +------------+------------------+--------+-----------------+------------------------------
 * |            |32.768KHz Crystal |        |                 |
 * +------------+------------------+--------+-----------------+------------------------------
 * |            |                  |  PA00  | XIN32           | EXTINT[0] SERCOM1/PAD[0] TCC2/WO[0]
 * |            |                  |  PA01  | XOUT32          | EXTINT[1] SERCOM1/PAD[1] TCC2/WO[1]
 * +------------+------------------+--------+-----------------+------------------------------
 */
```

zrecommerce, 2015-03-18:
Trying to upload at the moment using the following in boards.txt ...but the compiler is choking. It seems SERCOM4 and SERCOM5 are not defined (and shouldn't be for the SAMD21E18A). I'm attempting to fix.

```
#FEMTOUSB (WITH) BOOTLOADER - NATIVE PORT
femtousb.name=FemtoUSB
femtousb.vid.0=0x03eb
femtousb.pid.0=0x6124
femtousb.upload.tool=openocd
femtousb.upload.protocol=sam-ba
femtousb.upload.maximum_size=262144
femtousb.upload.use_1200bps_touch=false
femtousb.upload.wait_for_upload_port=false
femtousb.upload.native_usb=true
femtousb.build.mcu=cortex-m0plus
femtousb.build.f_cpu=48000000L
femtousb.build.usb_product="Femto.io"
femtousb.build.usb_manufacturer="Femtoduino"
femtousb.build.board=SAM_ZERO
femtousb.build.core=arduino
femtousb.build.extra_flags=-D__SAMD21E18A__ -mthumb {build.usb_flags}
femtousb.build.ldscript=linker_scripts/gcc/flash_with_bootloader.ld
femtousb.build.openocdscript=openocd_scripts/arduino_zero.cfg
femtousb.build.variant=arduino_zero
femtousb.build.variant_system_lib=
femtousb.build.vid=0x03eb
femtousb.build.pid=0x6124
femtousb.build.section.start=0x4000
```

zrecommerce, 2015-03-18:
As a matter of fact, `hardware/tools/CMSIS/Device/ATMEL/samd21/include/samd21e18.h` defines SERCOM0 through SERCOM3, but not SERCOM4 and SERCOM5. Doesn't exist on the SAMD21E18A, yet it's expected by the rest of the Arduino C++ scripts. Perhaps a "bug" in the arduino hardware files?

zrecommerce, 2015-03-18:
Using Arduino 1.5.8.3 (from Arduino.org, not Arduino.cc)

I used the following in boards.txt, modified SERCOM.cpp and variant.cpp.

`hardware/arduino/samd/boards.txt`
```
#FEMTOUSB (WITH) BOOTLOADER - NATIVE PORT
femtousb.name=FemtoUSB
femtousb.vid.0=0x03eb
femtousb.pid.0=0x6124
femtousb.upload.tool=openocd
femtousb.upload.protocol=sam-ba
femtousb.upload.maximum_size=262144
femtousb.upload.use_1200bps_touch=false
femtousb.upload.wait_for_upload_port=false
femtousb.upload.speed=57600
femtousb.upload.native_usb=true
femtousb.build.mcu=cortex-m0plus
femtousb.build.f_cpu=48000000L
femtousb.build.usb_product="Femto.io"
femtousb.build.usb_manufacturer="Femtoduino"
femtousb.build.board=SAM_ZERO
femtousb.build.core=arduino
femtousb.build.extra_flags=-D__SAMD21E18A__ -mthumb {build.usb_flags}
femtousb.build.ldscript=linker_scripts/gcc/flash_with_bootloader.ld
femtousb.build.openocdscript=openocd_scripts/arduino_zero.cfg
femtousb.build.variant=arduino_zero
femtousb.build.variant_system_lib=
femtousb.build.vid=0x03eb
femtousb.build.pid=0x6124
femtousb.build.section.start=0x4000
```

`hardware/arduino/samd/cores/arduino/SERCOM.cpp:588`
```
void SERCOM::initClockNVIC( void )
{
	uint8_t clockId = 0;
	IRQn_Type IdNvic;
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

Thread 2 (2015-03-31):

crystall less operation?

bobricius, 2015-03-31:
hi, I am arm newbie but I read somewhere that atsamd21 have crystall less usb operation, do you anybody tested any bootloader work without crystal?

zrecommerce, 2015-04-03:
According to the docs, it has internal clocks for this...but I've also read about issues (USB won't work?)

...I'll give it a go and see what happens

bobricius, 2015-04-03:
for compatbility with arduino zero I  have plan add 32khz crystall.

zrecommerce, 2015-06-18:
The SAM D21 should operate with a 48MHz crystal. I wouldn't recommend a crystal-less operation unless USB isn't a big deal.

Closed 2015-06-18.

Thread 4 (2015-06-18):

32MHz Crystal in the Schematic but 26MHz in the BOM/Partlist

michaelkroll, 2015-06-18:
Hi,
I recognized that the value for the crystal is different in the BOM and Schematic.
Is this a fault of on purpose.
Moreover it seems that the PCB on OSHPark does not yet include the crystal. Will you upload the PCB design with the crystal as well. I want to test the setting out you are providing here and already ordered the PCB from OSHPark and some parts from digikey. Thanks for your help.

Best
Michael.

zrecommerce, 2015-06-18:
Hello Michael,

I've updated the Gerbers, and BoM/Partslist for the FemtoUSB (QFN version, not QFP) in the latest commit to the master branch ( a8d56e28d1379ceb3dbb5027a026c719701cb8d2 )

If you need the most recent Bill of Materials, you can see my list on octopart as well:
https://octopart.com/bom-lookup/UgbhotEt

- Alex

Closed 2015-06-18.

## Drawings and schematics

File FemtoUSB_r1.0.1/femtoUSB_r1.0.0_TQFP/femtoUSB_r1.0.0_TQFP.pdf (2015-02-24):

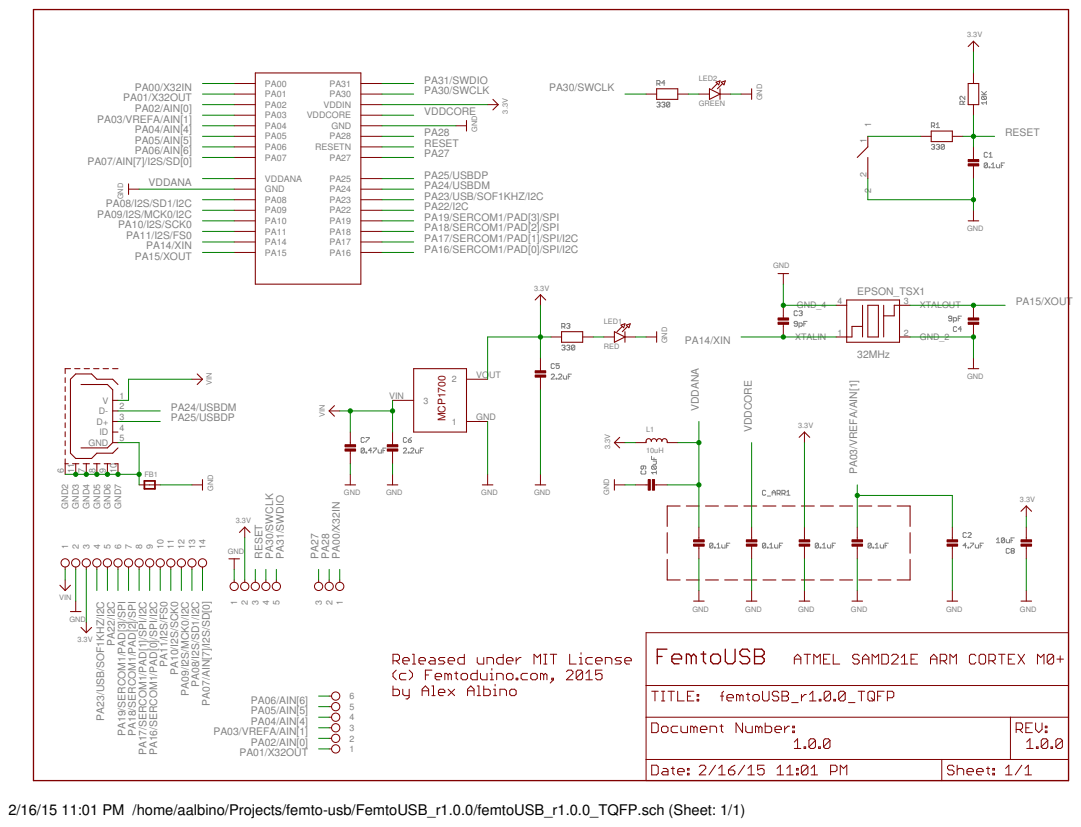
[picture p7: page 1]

VIN GND GND GND

2/16/15 11:01 PM /home/aalbino/Projects/femto-usb/FemtoUSB_r1.0.0/femtoUSB_r1.0.0_TQFP.sch (Sheet: 1/1)

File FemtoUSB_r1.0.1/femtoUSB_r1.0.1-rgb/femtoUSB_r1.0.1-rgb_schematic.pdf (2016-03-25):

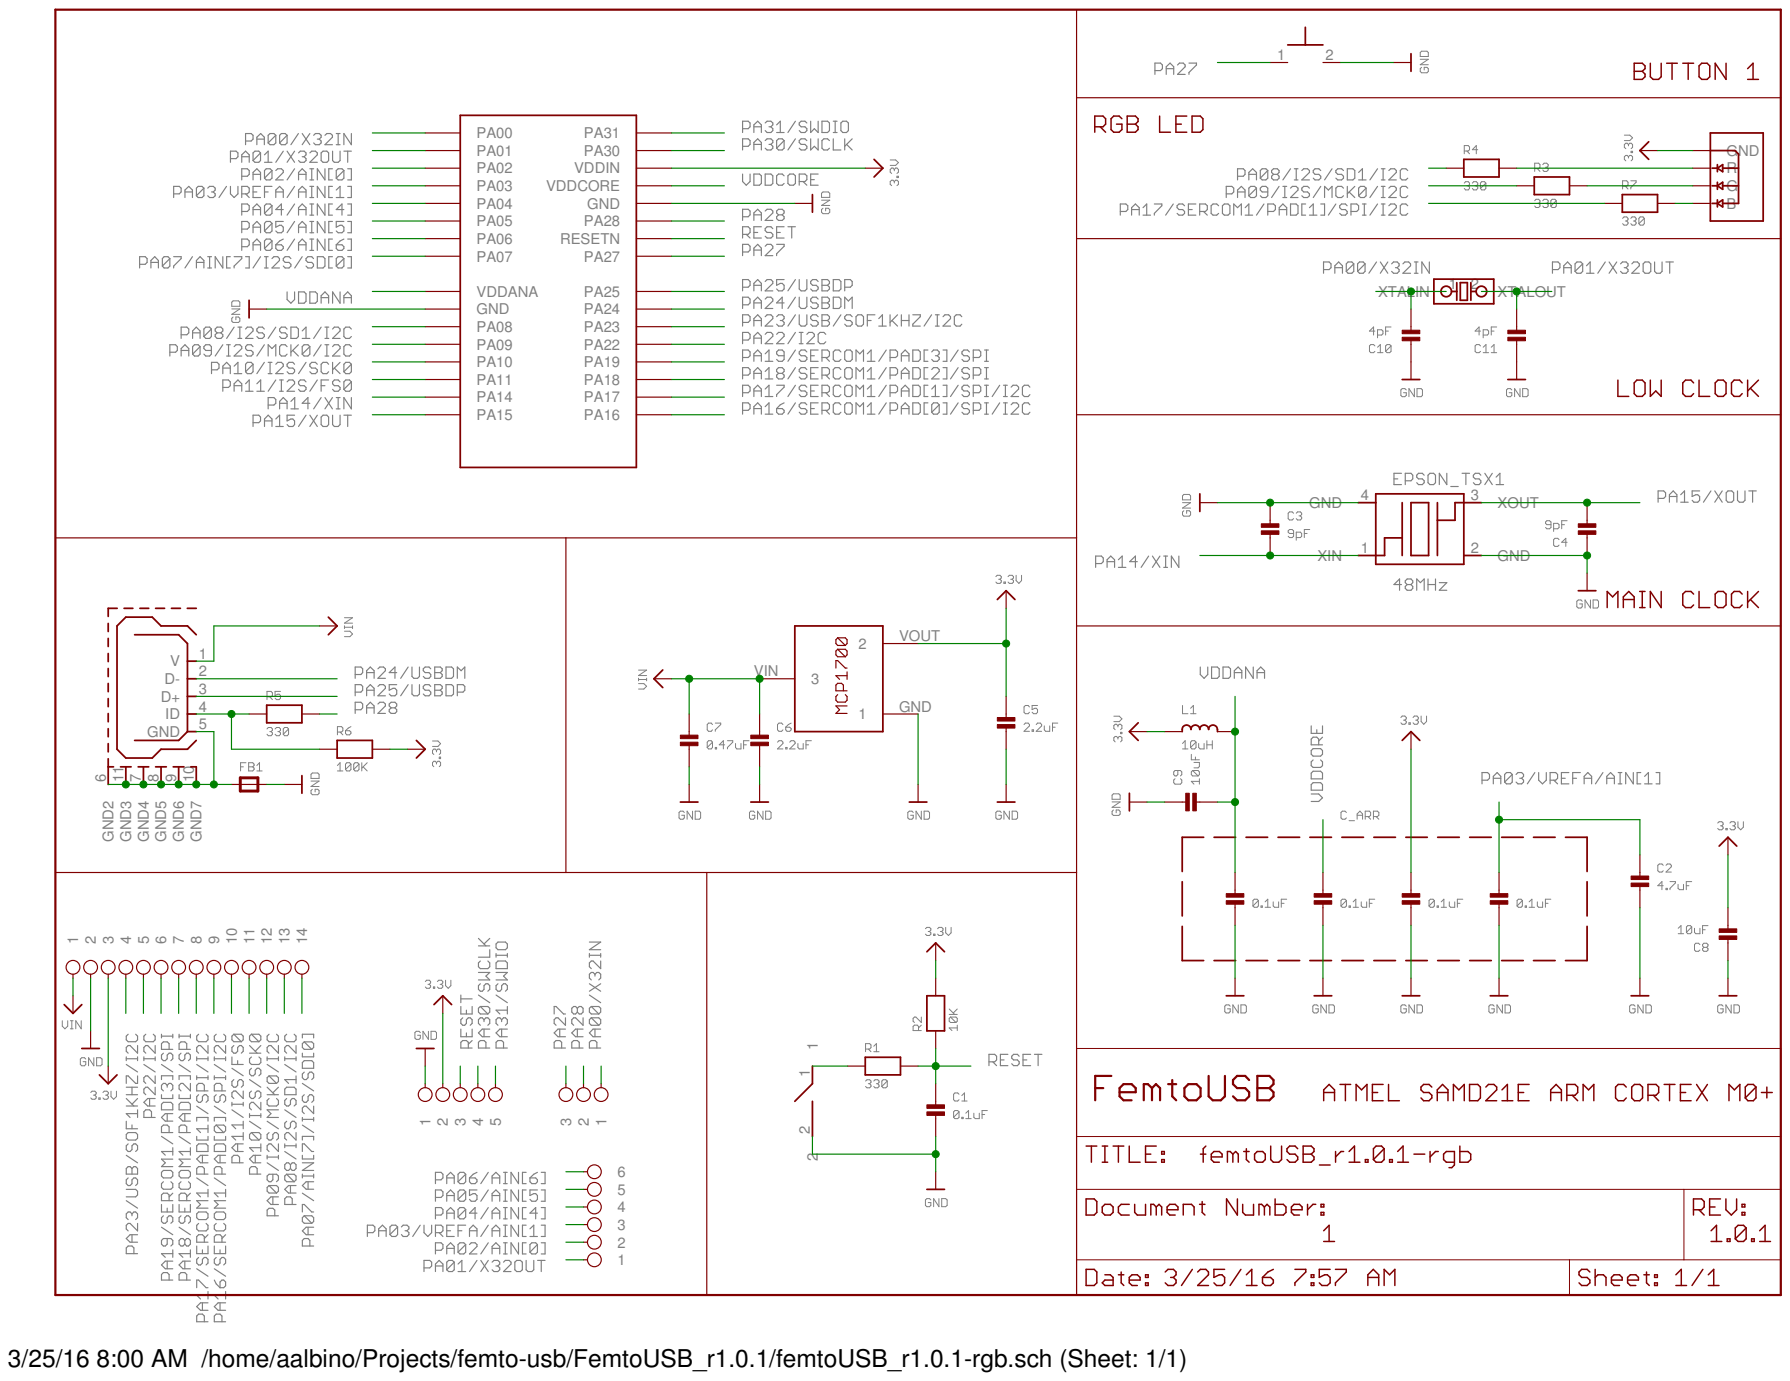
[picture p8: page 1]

3/25/16 8:00 AM /home/aalbino/Projects/femto-usb/FemtoUSB_r1.0.1/femtoUSB_r1.0.1-rgb.sch (Sheet: 1/1)

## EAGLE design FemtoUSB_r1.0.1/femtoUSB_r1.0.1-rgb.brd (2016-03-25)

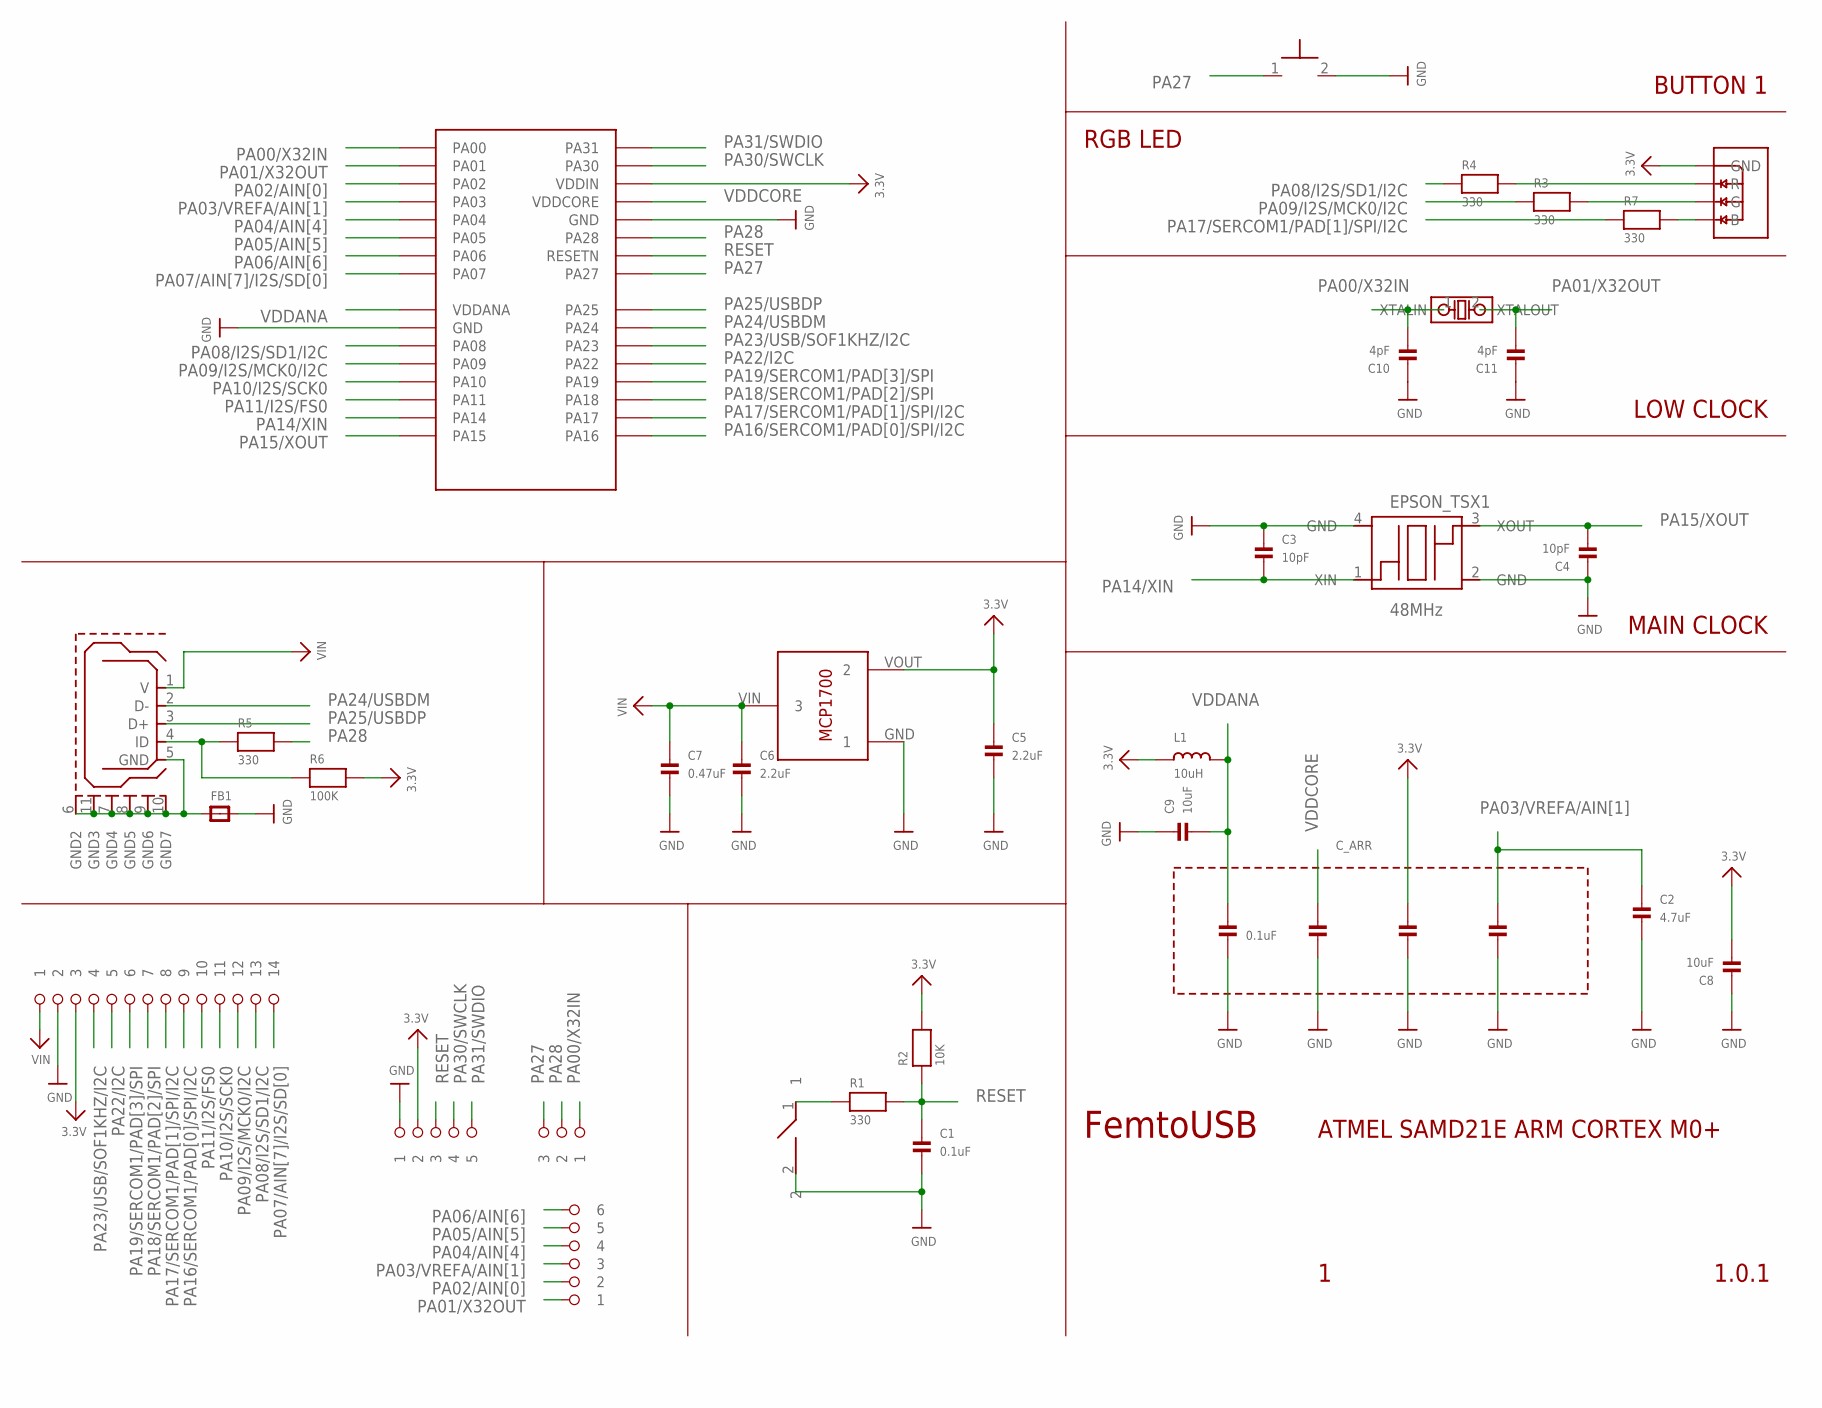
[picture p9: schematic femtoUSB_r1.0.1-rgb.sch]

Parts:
BTN_BOOT: TACTILE_SWITCH_NO_GND_NO_BOSS; SIDE_ACT_NO_GND_NO_BOSS
C1: 0.1uF; _0402MP
C2: 4.7uF; _0402MP
C3, C4: 10pF; _0402MP
C5, C6: 2.2uF; _0402MP
C7: 0.47uF; _0402MP
C8, C9: 10uF; _0402MP
C10, C11: 4pF; _0402MP
C_ARR: 0.1uF; CAPACITOR_ARRAY_1206_MONO_1X4
EPSON_TSX1: 48MHz; TSX-3225
FB1: FERRITE_0603MP; _0603MP
IC1: ATSAMD21E18A-MUT; QFN32
L1: 10uH; _0603MP
LDO_VREG: MCP1700T-3302E/TT
MICRO_B_USB: USB_MICROB; USB_MICROB_PACKAGE
OSC32K: ABS06-107-32.768KHZ-T
PIN_1X3: 1X3_ROUND
PIN_1X5: 1X5_ROUND
PIN_1X6: 1X6_ROUND
PIN_1X14: 1X14_ROUND
R1, R3, R4, R5, R7: 330; _0402MP
R2: 10K; _0402MP
R6: 100K; _0402MP
RGBLED: LRTB_R48G
SJ_RESET: SPST_SMD

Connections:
3.3V: C5.1, C8.2, C_ARR.5, IC1.30 (VDDIN), L1.1, LDO_VREG.VOUT (2), PIN_1X5.P$2 (2), PIN_1X14.P$3 (3), R2.2, R6.2, RGBLED.1 (GND)
GND: BTN_BOOT.2, C1.2, C2.2, C3.1, C4.1, C5.2, C6.2, C7.2, C8.1, C9.1, C10.1, C11.1, C_ARR.2, C_ARR.4, C_ARR.6, C_ARR.8, EPSON_TSX1.2 (GND), EPSON_TSX1.4 (GND), FB1.2, IC1.10 (GND), IC1.28 (GND), LDO_VREG.GND (1), PIN_1X5.P$1 (1), PIN_1X14.P$2 (2), SJ_RESET.2
unnamed: MICRO_B_USB.4 (ID), R5.1, R6.1
unnamed: R1.1, SJ_RESET.1
unnamed: FB1.1, MICRO_B_USB.5 (GND), MICRO_B_USB.6 (GND2), MICRO_B_USB.7 (GND4), MICRO_B_USB.8 (GND5), MICRO_B_USB.9 (GND6), MICRO_B_USB.10 (GND7), MICRO_B_USB.11 (GND3)
PA00/X32IN: C10.2, IC1.1 (PA00), OSC32K.1 (XTALIN), PIN_1X3.P$1 (1)
PA01/X32OUT: C11.2, IC1.2 (PA01), OSC32K.2 (XTALOUT), PIN_1X6.P$1 (1)
PA02/AIN[0]: IC1.3 (PA02), PIN_1X6.P$2 (2)
PA03/VREFA/AIN[1]: C2.1, C_ARR.7, IC1.4 (PA03), PIN_1X6.P$3 (3)
PA04/AIN[4]: IC1.5 (PA04), PIN_1X6.P$4 (4)
PA05/AIN[5]: IC1.6 (PA05), PIN_1X6.P$5 (5)
PA06/AIN[6]: IC1.7 (PA06), PIN_1X6.P$6 (6)
PA07/AIN[7]/I2S/SD[0]: IC1.8 (PA07), PIN_1X14.P$14 (14)
PA08/I2S/SD1/I2C: IC1.11 (PA08), PIN_1X14.P$13 (13), R4.1
PA08_R: R4.2, RGBLED.2 (R)
PA09/I2S/MCK0/I2C: IC1.12 (PA09), PIN_1X14.P$12 (12), R3.1
PA09_G: R3.2, RGBLED.3 (G)
PA10/I2S/SCK0: IC1.13 (PA10), PIN_1X14.P$11 (11)
PA11/I2S/FS0: IC1.14 (PA11), PIN_1X14.P$10 (10)
PA14/XIN: C3.2, EPSON_TSX1.1 (XIN), IC1.15 (PA14)
PA15/XOUT: C4.2, EPSON_TSX1.3 (XOUT), IC1.16 (PA15)
PA16/SERCOM1/PAD[0]/SPI/I2C: IC1.17 (PA16), PIN_1X14.P$9 (9)
PA17/SERCOM1/PAD[1]/SPI/I2C: IC1.18 (PA17), PIN_1X14.P$8 (8), R7.1
PA17_B: R7.2, RGBLED.4 (B)
PA18/SERCOM1/PAD[2]/SPI: IC1.19 (PA18), PIN_1X14.P$7 (7)
PA19/SERCOM1/PAD[3]/SPI: IC1.20 (PA19), PIN_1X14.P$6 (6)
PA22/I2C: IC1.21 (PA22), PIN_1X14.P$5 (5)
PA23/USB/SOF1KHZ/I2C: IC1.22 (PA23), PIN_1X14.P$4 (4)
PA24/USBDM: IC1.23 (PA24), MICRO_B_USB.2 (D-)
PA25/USBDP: IC1.24 (PA25), MICRO_B_USB.3 (D+)
PA27: BTN_BOOT.1, IC1.25 (PA27), PIN_1X3.P$3 (3)
PA28: IC1.27 (PA28), PIN_1X3.P$2 (2), R5.2
PA30/SWCLK: IC1.31 (PA30), PIN_1X5.P$4 (4)
PA31/SWDIO: IC1.32 (PA31), PIN_1X5.P$5 (5)
RESET: C1.1, IC1.26 (RESETN), PIN_1X5.P$3 (3), R1.2, R2.1
VDDANA: C9.2, C_ARR.1, IC1.9 (VDDANA), L1.2
VDDCORE: C_ARR.3, IC1.29 (VDDCORE)
VIN: C6.1, C7.1, LDO_VREG.VIN (3), MICRO_B_USB.1 (V), PIN_1X14.P$1 (1)

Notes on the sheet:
FemtoUSB
1.0.1
ATMEL SAMD21E ARM CORTEX M0+
MAIN CLOCK
LOW CLOCK
RGB LED
BUTTON 1

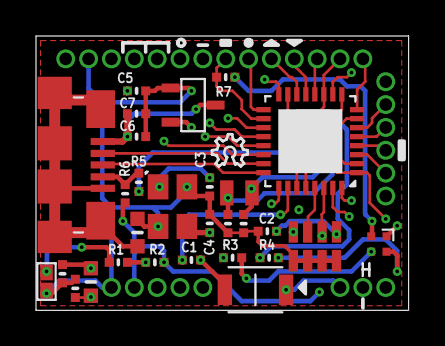
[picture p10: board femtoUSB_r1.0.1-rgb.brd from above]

Board: 4 copper layers, 20.7 x 15.2 mm, 34 parts (0 on the bottom side), 38 nets.

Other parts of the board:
U$35: OSHW_6X70_NOTEXT

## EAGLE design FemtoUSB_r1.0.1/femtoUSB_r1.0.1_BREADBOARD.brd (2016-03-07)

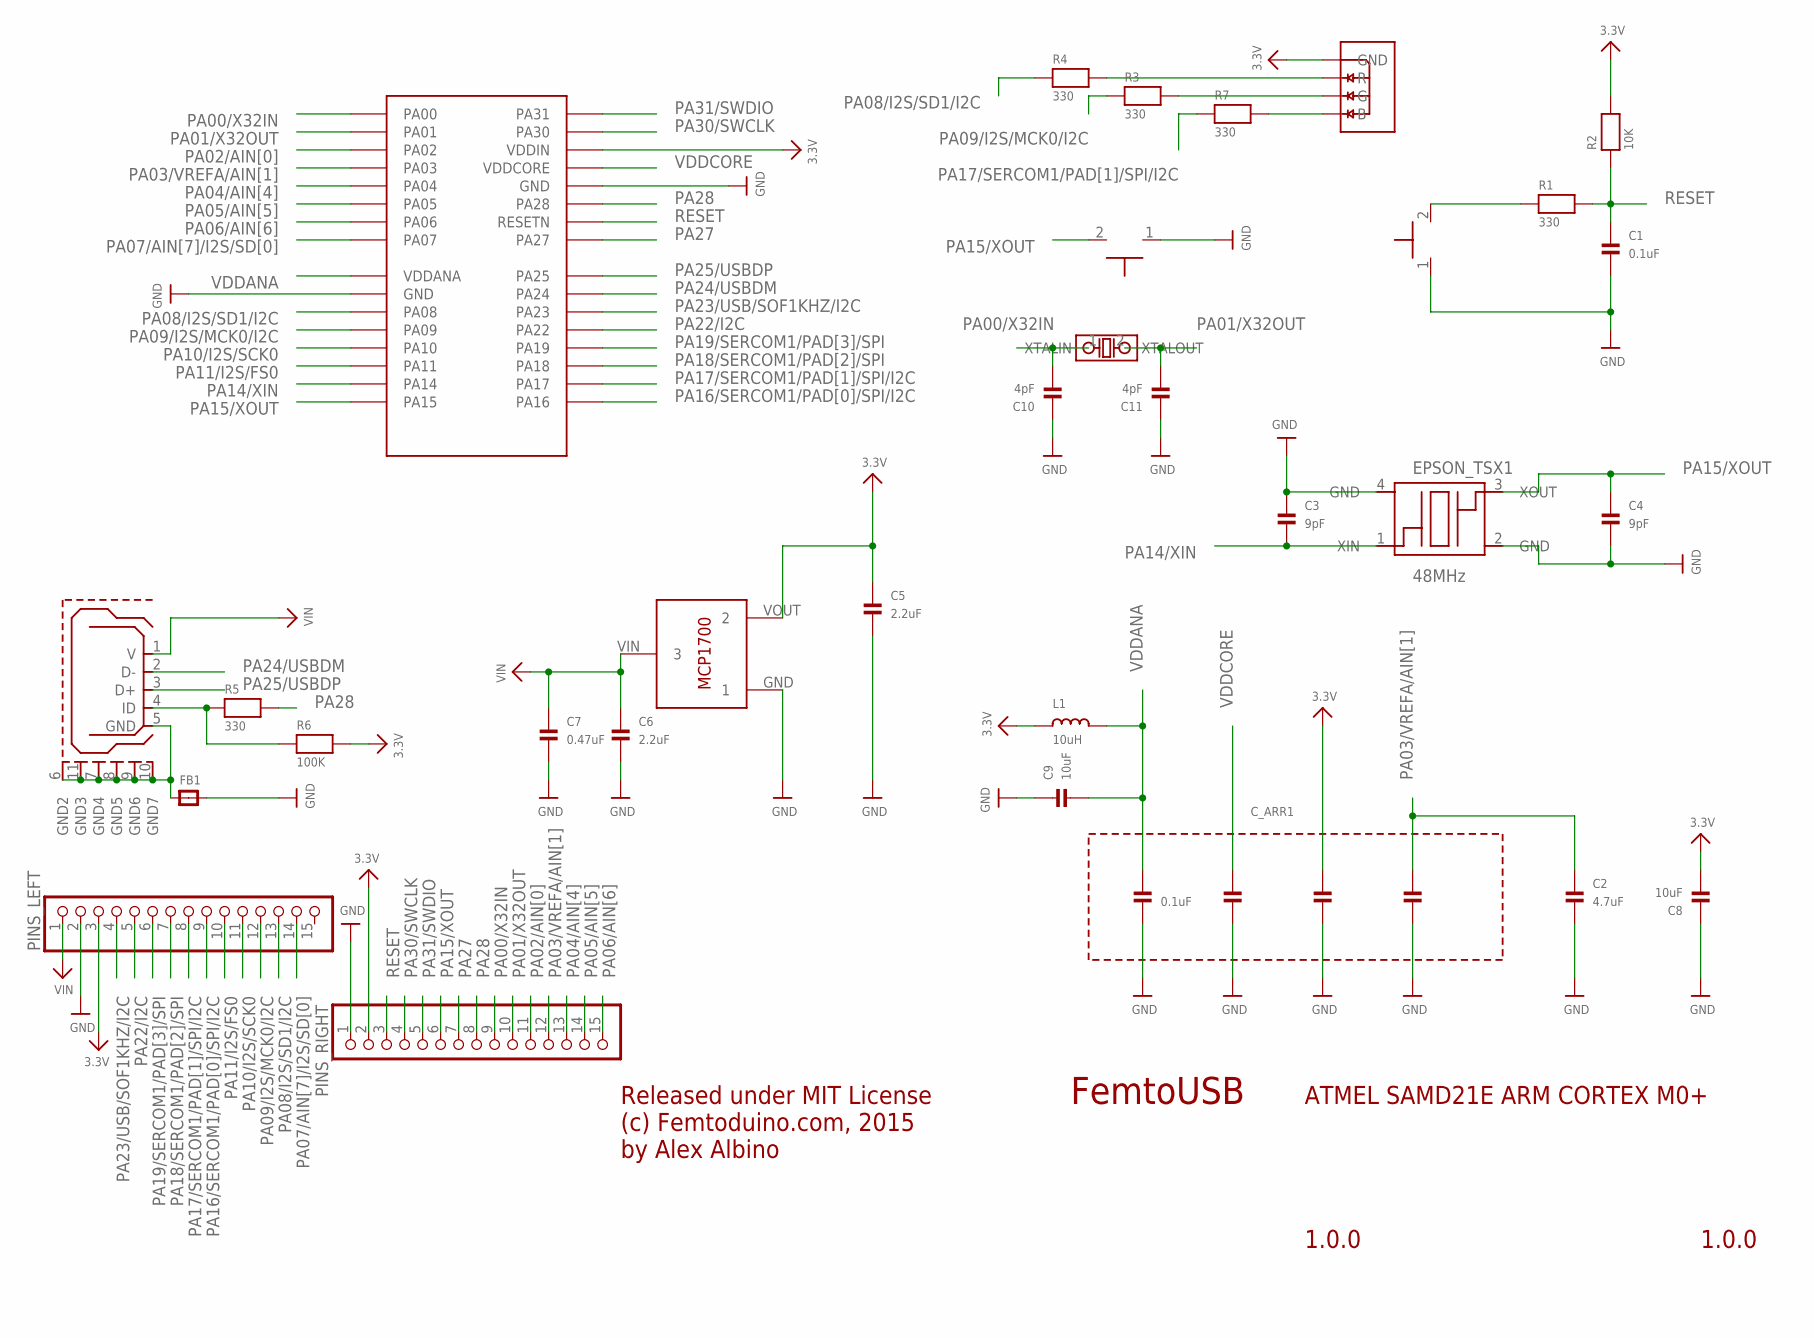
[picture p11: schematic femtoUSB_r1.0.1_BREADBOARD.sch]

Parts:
BOOT_BTN, BOOT_BTN1: TACTILE_SWITCH_NO_GND_NO_BOSS; SIDE_ACT_NO_GND_NO_BOSS
C1: 0.1uF; _0402MP; DIGIKEY_PART 445-4958-1-ND
C2: 4.7uF; _0402MP
C3, C4: 9pF; _0402MP
C5, C6: 2.2uF; _0402MP
C7: 0.47uF; _0402MP
C8, C9: 10uF; _0402MP
C10, C11: 4pF; _0402MP
C_ARR1: 0.1uF; CAPACITOR_ARRAY_1206_MONO_1X4
EPSON_TSX1: 48MHz; TSX-3225; DIGIKEY_PART TSX-3225 32.0000MF15X-B-ND
FB1: FERRITE_0603MP; _0603MP
IC1: ATSAMD21E18A-MUT; QFN32; DIGIKEY_PART ATSAMD21E18A-AU-ND
L1: 10uH; _0603MP
LDO_VREG: MCP1700T-3302E/TT
MICRO_B_USB: USB_MICROB; USB_MICROB_PACKAGE
PINS_LEFT: HEADER-1X15; 1X15_ROUND_70
PINS_RIGHT: HEADER-1X15; 1X15_ROUND_70
R1: 330; _0402MP; DIGIKEY_PART 541-330JCT-ND
R2: 10K; _0402MP
R3, R4, R5, R7: 330; _0402MP
R6: 100K; _0402MP
RGBLED: LRTB_R48G
U$40: ABS06-107-32.768KHZ-T

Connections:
3.3V: C5.1, C8.2, C_ARR1.5, IC1.30 (VDDIN), L1.1, LDO_VREG.VOUT (2), PINS_LEFT.3, PINS_RIGHT.2, R2.2, R6.2, RGBLED.1 (GND)
GND: BOOT_BTN.1, BOOT_BTN1.1, C1.2, C2.2, C3.1, C4.2, C5.2, C6.2, C7.2, C8.1, C9.1, C10.1, C11.1, C_ARR1.2, C_ARR1.4, C_ARR1.6, C_ARR1.8, EPSON_TSX1.2 (GND), EPSON_TSX1.4 (GND), FB1.2, IC1.10 (GND), IC1.28 (GND), LDO_VREG.GND (1), PINS_LEFT.2, PINS_RIGHT.1
GND_RAW: FB1.1, MICRO_B_USB.5 (GND), MICRO_B_USB.6 (GND2), MICRO_B_USB.7 (GND4), MICRO_B_USB.8 (GND5), MICRO_B_USB.9 (GND6), MICRO_B_USB.10 (GND7), MICRO_B_USB.11 (GND3)
unnamed: MICRO_B_USB.4 (ID), R5.1, R6.1
unnamed: BOOT_BTN1.2, R1.1
PA00/X32IN: C10.2, IC1.1 (PA00), PINS_RIGHT.9, U$40.1 (XTALIN)
PA01/X32OUT: C11.2, IC1.2 (PA01), PINS_RIGHT.10, U$40.2 (XTALOUT)
PA02/AIN[0]: IC1.3 (PA02), PINS_RIGHT.11
PA03/VREFA/AIN[1]: C2.1, C_ARR1.7, IC1.4 (PA03), PINS_RIGHT.12
PA04/AIN[4]: IC1.5 (PA04), PINS_RIGHT.13
PA05/AIN[5]: IC1.6 (PA05), PINS_RIGHT.14
PA06/AIN[6]: IC1.7 (PA06), PINS_RIGHT.15
PA07/AIN[7]/I2S/SD[0]: IC1.8 (PA07), PINS_LEFT.14
PA08/I2S/SD1/I2C: IC1.11 (PA08), PINS_LEFT.13, R4.1
PA08_R: R4.2, RGBLED.2 (R)
PA09/I2S/MCK0/I2C: IC1.12 (PA09), PINS_LEFT.12, R3.1
PA09_G: R3.2, RGBLED.3 (G)
PA10/I2S/SCK0: IC1.13 (PA10), PINS_LEFT.11
PA11/I2S/FS0: IC1.14 (PA11), PINS_LEFT.10
PA14/XIN: C3.2, EPSON_TSX1.1 (XIN), IC1.15 (PA14)
PA15/XOUT: BOOT_BTN.2, C4.1, EPSON_TSX1.3 (XOUT), IC1.16 (PA15), PINS_RIGHT.6
PA16/SERCOM1/PAD[0]/SPI/I2C: IC1.17 (PA16), PINS_LEFT.9
PA17/SERCOM1/PAD[1]/SPI/I2C: IC1.18 (PA17), PINS_LEFT.8, R7.1
PA17_B: R7.2, RGBLED.4 (B)
PA18/SERCOM1/PAD[2]/SPI: IC1.19 (PA18), PINS_LEFT.7
PA19/SERCOM1/PAD[3]/SPI: IC1.20 (PA19), PINS_LEFT.6
PA22/I2C: IC1.21 (PA22), PINS_LEFT.5
PA23/USB/SOF1KHZ/I2C: IC1.22 (PA23), PINS_LEFT.4
PA24/USBDM: IC1.23 (PA24), MICRO_B_USB.2 (D-)
PA25/USBDP: IC1.24 (PA25), MICRO_B_USB.3 (D+)
PA27: IC1.25 (PA27), PINS_RIGHT.7
PA28: IC1.27 (PA28), PINS_RIGHT.8, R5.2
PA30/SWCLK: IC1.31 (PA30), PINS_RIGHT.4
PA31/SWDIO: IC1.32 (PA31), PINS_RIGHT.5
RESET: C1.1, IC1.26 (RESETN), PINS_RIGHT.3, R1.2, R2.1
VDDANA: C9.2, C_ARR1.1, IC1.9 (VDDANA), L1.2
VDDCORE: C_ARR1.3, IC1.29 (VDDCORE)
VIN: C6.1, C7.1, LDO_VREG.VIN (3), MICRO_B_USB.1 (V), PINS_LEFT.1

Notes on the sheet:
FemtoUSB
1.0.0
ATMEL SAMD21E ARM CORTEX M0+
Released under MIT License (c) Femtoduino.com, 2015 by Alex Albino

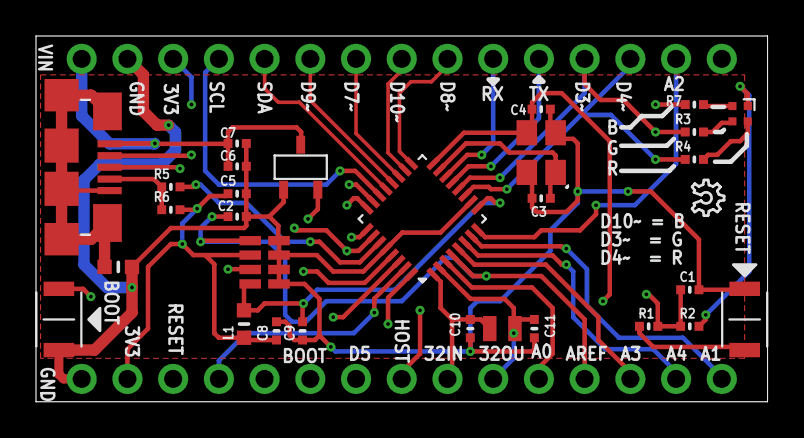
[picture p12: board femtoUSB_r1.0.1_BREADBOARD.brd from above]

Board: 4 copper layers, 40.6 x 20.3 mm, 32 parts (0 on the bottom side), 38 nets.

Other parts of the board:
OSH_LOGO: OSHW_6X70_NOTEXT

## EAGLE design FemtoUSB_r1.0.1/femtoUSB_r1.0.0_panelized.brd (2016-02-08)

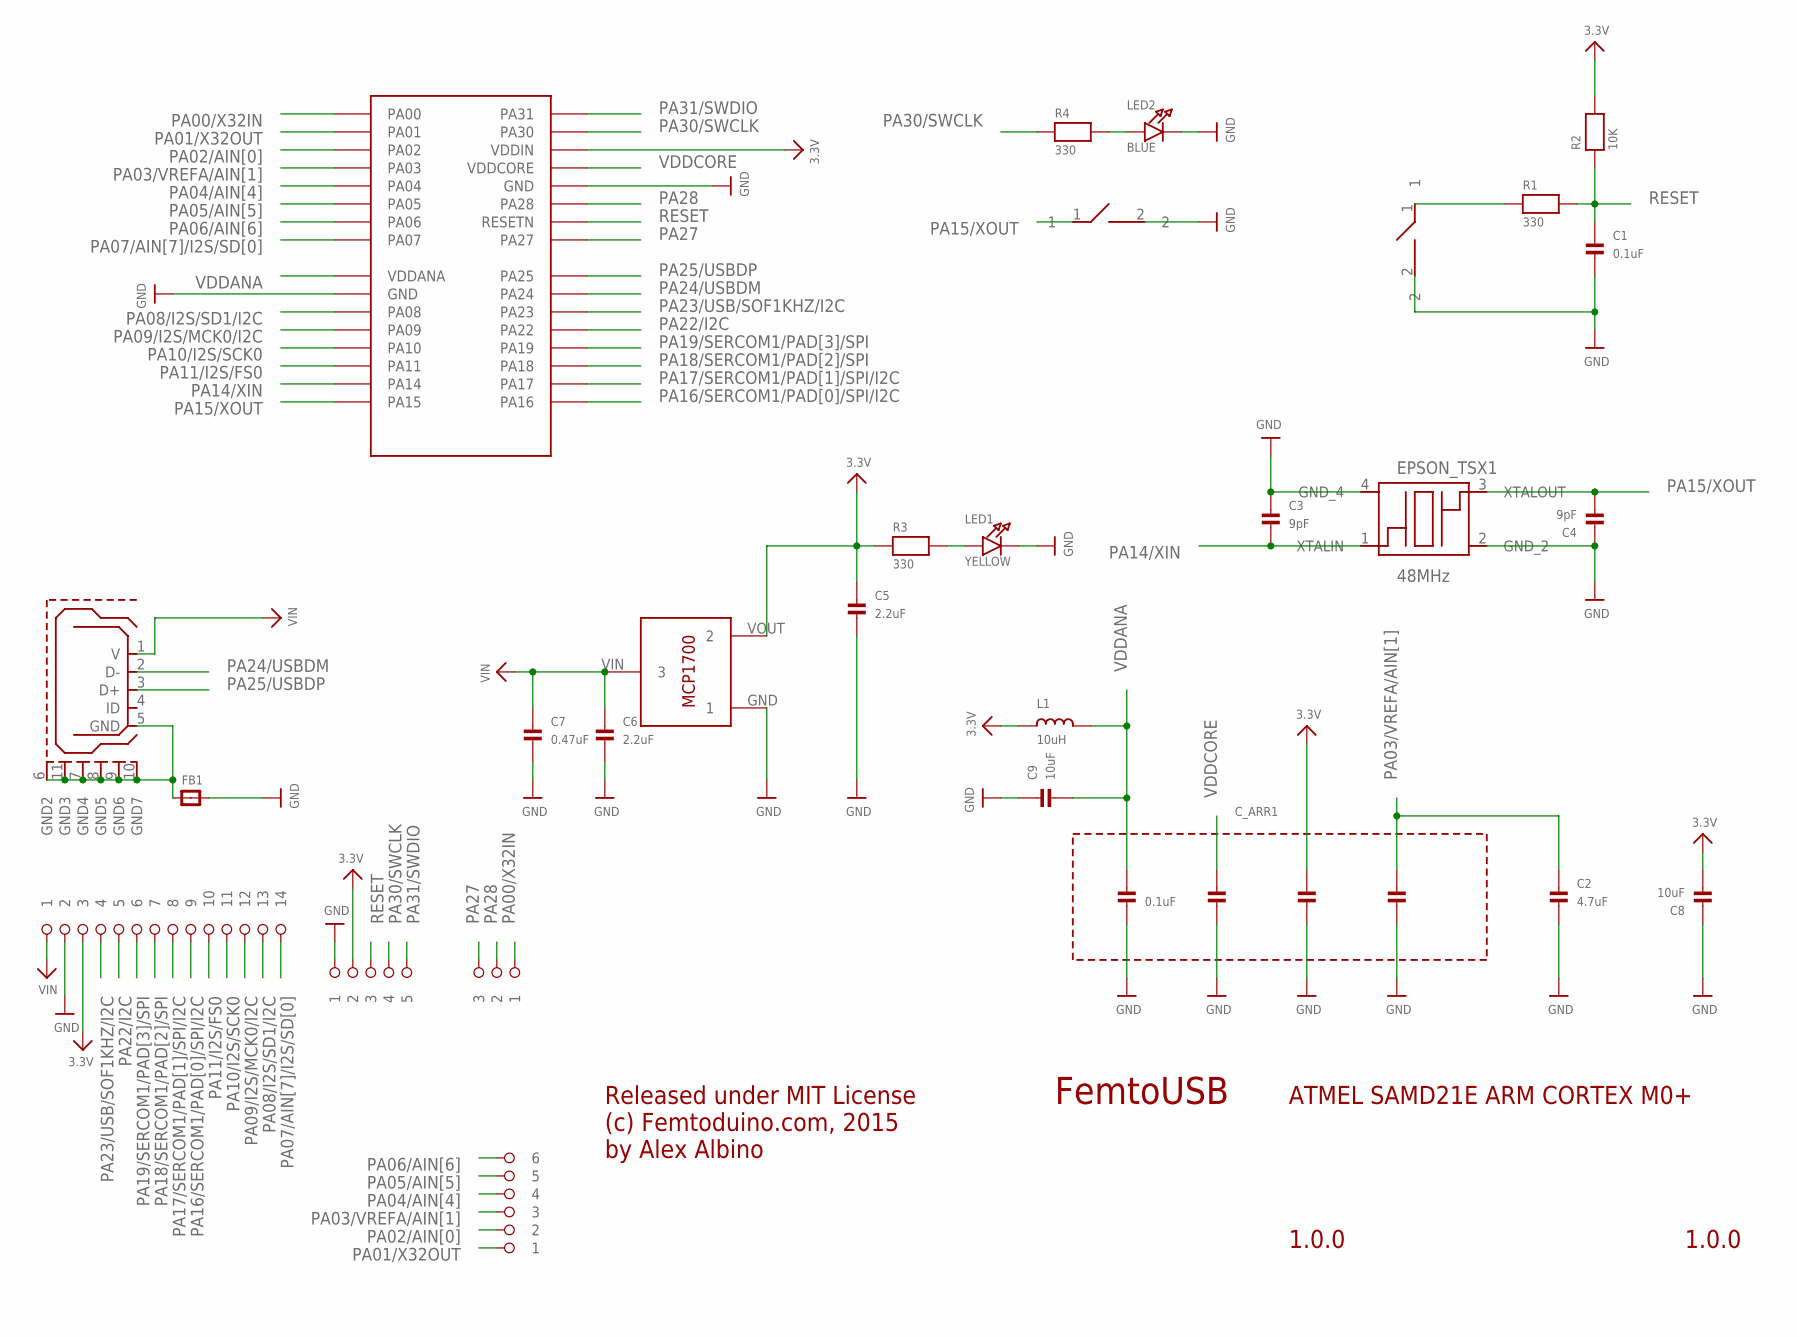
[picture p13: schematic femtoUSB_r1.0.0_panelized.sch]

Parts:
BTN: OMRON B3U-300P(M); SPST_SMD
C1: 0.1uF; _0402MP
C2: 4.7uF; _0402MP
C3, C4: 9pF; _0402MP
C5, C6: 2.2uF; _0402MP
C7: 0.47uF; _0402MP
C8, C9: 10uF; _0402MP
C_ARR1: 0.1uF; CAPACITOR_ARRAY_1206_MONO_1X4
EPSON_TSX1: 48MHz; TSX-3225; DIGIKEY_PART TSX-3225 32.0000MF15X-B-ND
FB1: FERRITE_0603MP; _0603MP
IC1: ATSAMD21E18A-MUT; QFN32
L1: 10uH; _0603MP
LDO_VREG: MCP1700T-3302E/TT
LED1: YELLOW; CHIPLED_0603_NOOUTLINE
LED2: BLUE; CHIPLED_0603_NOOUTLINE
MICRO_B_USB: USB_MICROB; USB_MICROB_PACKAGE
R1, R3, R4: 330; _0402MP
R2: 10K; _0402MP
U$6: 1X14_ROUND
U$7: 1X3_ROUND
U$9: 1X5_ROUND
U$12: 1X6_ROUND
U$38: SPST_SMD

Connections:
3.3V: C5.1, C8.2, C_ARR1.5, IC1.30 (VDDIN), L1.1, LDO_VREG.VOUT (2), R2.2, R3.1, U$6.P$3 (3), U$9.P$2 (2)
GND: BTN.2, C1.2, C2.2, C3.1, C4.1, C5.2, C6.2, C7.2, C8.1, C9.1, C_ARR1.2, C_ARR1.4, C_ARR1.6, C_ARR1.8, EPSON_TSX1.2 (GND_2), EPSON_TSX1.4 (GND_4), FB1.2, IC1.10 (GND), IC1.28 (GND), LDO_VREG.GND (1), LED1.C, LED2.C, U$6.P$2 (2), U$9.P$1 (1), U$38.2
unnamed: LED1.A, R3.2
unnamed: LED2.A, R4.2
unnamed: BTN.1, R1.1
unnamed: FB1.1, MICRO_B_USB.5 (GND), MICRO_B_USB.6 (GND2), MICRO_B_USB.7 (GND4), MICRO_B_USB.8 (GND5), MICRO_B_USB.9 (GND6), MICRO_B_USB.10 (GND7), MICRO_B_USB.11 (GND3)
PA00/X32IN: IC1.1 (PA00), U$7.P$1 (1)
PA01/X32OUT: IC1.2 (PA01), U$12.P$1 (1)
PA02/AIN[0]: IC1.3 (PA02), U$12.P$2 (2)
PA03/VREFA/AIN[1]: C2.1, C_ARR1.7, IC1.4 (PA03), U$12.P$3 (3)
PA04/AIN[4]: IC1.5 (PA04), U$12.P$4 (4)
PA05/AIN[5]: IC1.6 (PA05), U$12.P$5 (5)
PA06/AIN[6]: IC1.7 (PA06), U$12.P$6 (6)
PA07/AIN[7]/I2S/SD[0]: IC1.8 (PA07), U$6.P$14 (14)
PA08/I2S/SD1/I2C: IC1.11 (PA08), U$6.P$13 (13)
PA09/I2S/MCK0/I2C: IC1.12 (PA09), U$6.P$12 (12)
PA10/I2S/SCK0: IC1.13 (PA10), U$6.P$11 (11)
PA11/I2S/FS0: IC1.14 (PA11), U$6.P$10 (10)
PA14/XIN: C3.2, EPSON_TSX1.1 (XTALIN), IC1.15 (PA14)
PA15/XOUT: C4.2, EPSON_TSX1.3 (XTALOUT), IC1.16 (PA15), U$38.1
PA16/SERCOM1/PAD[0]/SPI/I2C: IC1.17 (PA16), U$6.P$9 (9)
PA17/SERCOM1/PAD[1]/SPI/I2C: IC1.18 (PA17), U$6.P$8 (8)
PA18/SERCOM1/PAD[2]/SPI: IC1.19 (PA18), U$6.P$7 (7)
PA19/SERCOM1/PAD[3]/SPI: IC1.20 (PA19), U$6.P$6 (6)
PA22/I2C: IC1.21 (PA22), U$6.P$5 (5)
PA23/USB/SOF1KHZ/I2C: IC1.22 (PA23), U$6.P$4 (4)
PA24/USBDM: IC1.23 (PA24), MICRO_B_USB.2 (D-)
PA25/USBDP: IC1.24 (PA25), MICRO_B_USB.3 (D+)
PA27: IC1.25 (PA27), U$7.P$3 (3)
PA28: IC1.27 (PA28), U$7.P$2 (2)
PA30/SWCLK: IC1.31 (PA30), R4.1, U$9.P$4 (4)
PA31/SWDIO: IC1.32 (PA31), U$9.P$5 (5)
RESET: C1.1, IC1.26 (RESETN), R1.2, R2.1, U$9.P$3 (3)
VDDANA: C9.2, C_ARR1.1, IC1.9 (VDDANA), L1.2
VDDCORE: C_ARR1.3, IC1.29 (VDDCORE)
VIN: C6.1, C7.1, LDO_VREG.VIN (3), MICRO_B_USB.1 (V), U$6.P$1 (1)

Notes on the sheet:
FemtoUSB
1.0.0
ATMEL SAMD21E ARM CORTEX M0+
Released under MIT License (c) Femtoduino.com, 2015 by Alex Albino

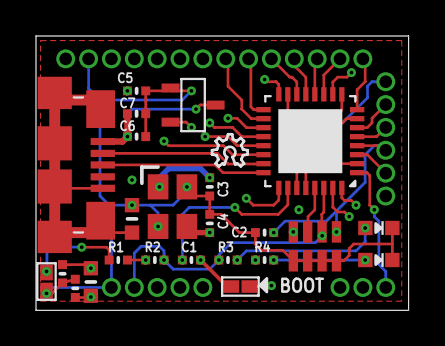
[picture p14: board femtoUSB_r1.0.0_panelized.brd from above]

Board: 4 copper layers, 20.7 x 15.2 mm, 29 parts (0 on the bottom side), 36 nets.

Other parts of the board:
U$35: OSHW_6X70_NOTEXT

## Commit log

2015-01-06 Initial release 1.0.0
    [femtoUSB_r1.0.0.brd, femtoUSB_r1.0.0.sch, femtoUSB_r1.0.0_bom.csv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]
2015-01-06 Adding TQFP chip variety
    [femtoUSB_r1.0.0_TQFP.brd, femtoUSB_r1.0.0_TQFP.sch, femtoUSB_r1.0.0_TQFP_bom.csv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]
2015-01-22 Corrected the Make and model of the LDO Voltage Regulator. Board now powers on.
    [femtoUSB_r1.0.0.brd, femtoUSB_r1.0.0.sch, femtoUSB_r1.0.0_TQFP.brd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]
2015-02-01 Corrected the snubbing circuits by adding the missing 10uH inductor, and two missing 10uF capacitors. Also corrected the connection from VDDIN pin to 3V3
    [femtoUSB_r1.0.0_TQFP.brd, femtoUSB_r1.0.0_TQFP.sch, femtoUSB_r1.0.0_TQFP_bom.csv]
2015-02-15 Updating README to include basic welcome for makers transitioning from AVR to ARM, along with setup and build instructions
2015-02-17 Updating the QFN (no leads) chip version of the board - adding in missing 10uF caps and 10uH inductor
    [femtoUSB_r1.0.0.brd, femtoUSB_r1.0.0.sch]
2015-02-17 Adding in PDFs, removing Notice labels, as boards appear to work now
    [femtoUSB_r1.0.0.sch, femtoUSB_r1.0.0_TQFP.sch]
2015-02-24 adding in fuse values from Atmel Studio
2015-03-20 Updating r1.x version of FemtoUSB (QFN and QFP chip version). Pin PA15 and GND pads now available to start board up in bootloader mode (SAM-BA)
    [femtoUSB_r1.0.0.brd, femtoUSB_r1.0.0.sch, femtoUSB_r1.0.0_TQFP.brd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]
2015-03-28 Releasing the bread-board friendly variant of the FemtoUSB ARM board
    [femtoUSB_r1.0.0_TQFP_BREADBOARD.brd, femtoUSB_r1.0.0_TQFP_BREADBOARD.sch]
2015-04-16 Adding OpenOCD config file, and notes about boot loading using non-windows machines
    [atmel_samd21e18a.cfg]
2015-04-28 Adding in bare chip config for ATSAMR21E18A, which is just a SAM D21 + AT86RF233 integrated, and hooked up internally to certain GPIO pins
    [atmel_samr21e18a.cfg]
2015-06-18 Updating gerbers and BoM/Partslist of QFN version
    [femtoUSB_r1.0.0.brd, femtoUSB_r1.0.0.sch, femtoUSB_r1.0.0_TQFP.brd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]
2016-02-08 Updating FemtoUSB to r1.0.1 (EXPERIMENTAL)
    [femtoUSB_r1.0.0_TQFP.brd, femtoUSB_r1.0.0_TQFP_BREADBOARD.brd, femtoUSB_r1.0.0_TQFP_BREADBOARD.sch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]
2016-02-12 Our first Arduino example for the Atme ATSAMD21E18 based FemtoUSB
2016-02-14 Adding femtoUSB_r1.0.1-rgb design. Uses RGB LED instead of standard SMD LEDs
    [femtoUSB_r1.0.1-rgb.brd, femtoUSB_r1.0.1-rgb.sch]
2016-02-16 Updating breadboard version. Adjusting USB ID pin connection back to PA28 on both FemtoUSB, and FemtoUSB breadboard layout
    [femtoUSB_r1.0.1-rgb.brd, femtoUSB_r1.0.1_BREADBOARD.brd, femtoUSB_r1.0.1_BREADBOARD.sch]
2016-02-16 Updating FemtoUSB r1.0.1 breadboard version
    [femtoUSB_r1.0.1_BREADBOARD.brd]
2016-02-16 Updating FemtoUSB Breadboard desing. Using QFN only
    [femtoUSB_r1.0.0_TQFP_BREADBOARD.brd, femtoUSB_r1.0.0_TQFP_BREADBOARD.sch, femtoUSB_r1.0.1_BREADBOARD.brd]
2016-03-07 Updating FemtoUSB r1.0.1 w/ RGB. Silkscreen updated to reflect Arduino pin assignments
    [femtoUSB_r1.0.1-rgb.brd, femtoUSB_r1.0.1-rgb.csv, femtoUSB_r1.0.1-rgb.sch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]
2016-03-07 Updating cap value for 32.768KHz crystal to correct value, adding in example sketches
    [femtoUSB_r1.0.1-rgb.brd, femtoUSB_r1.0.1-rgb.sch]
2016-03-07 Updating Bill of Materials, and component attributes to include mfr ID. Button is now used by PA27 instead of PA15 (boot), since Arduino core doesn't need the boot pin to upload subsequent sketches
    [femtoUSB_r1.0.1-rgb.brd, femtoUSB_r1.0.1-rgb.csv, femtoUSB_r1.0.1-rgb.sch]
2016-03-25 Caps for 48MHz updated from 9pF to 10pF. Updated to correct manufacturor ID for too. Minor fix to skewed polygon - was supposed to be rectangular.
    [atmel_samd21e18a.cfg, atmel_samr21e18a.cfg, femtoUSB_r1.0.1-rgb.brd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]

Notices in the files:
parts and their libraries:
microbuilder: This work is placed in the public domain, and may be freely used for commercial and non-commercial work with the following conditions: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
